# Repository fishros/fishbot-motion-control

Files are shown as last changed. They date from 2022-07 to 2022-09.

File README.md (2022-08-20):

# FishBot机器人运动控制板子-嵌入式驱动原理图PCB

## TODO&DONE
- [x] 电机驱动\编码器计算 
- [x] OLED驱动与显示
- [x] WIFI模块
- [x] 电机PID控制计算
- [x] Protocol数据接受及处理实现
- [x] Protocol数据发送处理及实现
- [x] MPU6050任务数据获取及姿态推算
- [x] UDP协议收发任务实现
- [ ] WIFI短线自动重连
- [ ] NVS掉电存储模块（WIFI配置、PID配置）
- [ ] 按键驱动实现（模式切换功能）
- [ ] 日志模块搭建（支持输出到UDPServer）
- [ ] 重新分配各个任务的优先级及空间大小
- [ ] 制定新版本协议（支持模式配置、WIFI配置，增加PID更多参数，冗余电机数量）
- [ ] 新版本协议WIFI模块实现
- [ ] 新版本协议PID模块实现
- [ ] 新版本协议电机模块实现

## 开发环境搭建

### 构建
```
docker run -it  --rm --privileged -v=/dev:/dev  -v `pwd`:`pwd` -w `pwd` espressif/idf:release-v4.4 idf.py build
```

### 查看

```
docker run -it  --rm --privileged -v=/dev:/dev  -v `pwd`:`pwd` -w `pwd` espressif/idf:release-v4.4 idf.py monitor
```

### 烧写
```
docker run -it  --rm --privileged -v=/dev:/dev  -v `pwd`:`pwd` -w `pwd` espressif/idf:release-v4.4 idf.py flash monitor
# Windows With Docker&WSL
esptool.py -p /dev/ttyS12 -b 921600  --before=default_reset --after=hard_reset write_flash --flash_mode dio --flash_freq 40m --flash_size 4MB 0x1000 bootloader/bootloader.bin 0x10000 main.bin 0x8000 partition_table/partition-table.bin
```

### Merge
```
docker run -it --rm --privileged -v=/dev:/dev  -v `pwd`:`pwd` -w `pwd` fishros2/fishbot-tool esptool.py --chip ESP8266 merge_bin -o fishbot_motion_control_v1.0.0.`date +%y%m%d`.bin --flash_mode dio --flash_size 4MB 0x1000 build/bootloader/bootloader.bin 0x8000 build/partition_table/partition-table.bin 0x10000 build/main.bin
```

## 工程介绍

```mermaid
graph TD;
protocol-->key
protocol-->motor
protocol-->oled
protocol-->imu
protocol-->wifi
key-->fishbot
motor-->fishbot
oled-->fishbot
imu-->fishbot
wifi-->fishbot
```

### 嵌入式驱动结构

目前组件目录

```
├── config
│   └── include
│       ├── config.h
│       └── task_config.h
├── drivers
│   ├── general
│   │   ├── key
│   │   ├── led
│   │   │   ├── include
│   │   │   │   └── led.h
│   │   │   └── led_esp32.c
│   │   ├── motors
│   │   │   └── motor
│   │   │       ├── include
│   │   │       │   └── motor.h
│   │   │       └── motor.c
│   │   └── wifi
│   │       ├── include
│   │       │   └── wifi.h
│   │       └── wifi.c
│   └── i2c_devices
│       ├── mpu6050
│       │   ├── include
│       │   │   ├── mpu6050.h
│       │   │   └── mpu6050_registers.h
│       │   └── mpu6050.c
│       └── oled
│           ├── include
│           │   └── oled.h
│           └── oled.c
├── fishbot
│   ├── fishbot.c
│   ├── fishbot_config.c
│   └── include
│       ├── fishbot_config.h
│       └── fishbot.h
├── libs
│   ├── esp32_i2c_rw
│   │   ├── esp32_i2c_rw.c
│   │   └── include
│   │       └── esp32_i2c_rw.h
│   ├── pid_controller
│   │   ├── include
│   │   │   └── pid_controller.h
│   │   └── pid_controller.c
│   └── rotary_encoder
│       ├── include
│       │   └── rotary_encoder.h
│       └── src
│           └── rotary_encoder_pcnt_ec11.c
└── protocol
    ├── proto
    │   ├── include
    │   │   └── protocol.h
    │   └── protocol.c
    ├── proto_utils
    │   ├── include
    │   │   ├── proto_utils.h
    │   │   └── proto_v1.0.0.20220621.h
    │   ├── proto_utils.c
    │   └── proto_v1.0.0.20220621.c
    ├── uart_protocol
    │   ├── include
    │   │   └── uart_protocol.h
    │   └── uart_protocol.c
    └── udp_client_protocol
        ├── include
        │   └── udp_client_protocol.h
        └── udp_client.c
```

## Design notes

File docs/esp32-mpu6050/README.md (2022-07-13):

# ESP32 MPU6050

Code provided in this repository is a MPU6050 library for ESP 32.

## Table of Contents

- [Components](#components)
  - [ESP 32](#esp-32)
  - [ESP-IDF](#esp-idf)
  - [MPU-6050](#mpu-6050)
- [Quick Start](#quick-start)
- [Acknowledgments](#acknowledgments)

## Components

To make this code work, you need the following components:

* This repository.
* [ESP 32](https://espressif.com/en/products/hardware/esp32/overview) module.
* [ESP-IDF](https://github.com/espressif/esp-idf).
* [MPU-6050](https://www.invensense.com/products/motion-tracking/6-axis/mpu-6050/) module.

### ESP 32

Any ESP 32 module should work.

### ESP-IDF

Configure your PC according to [ESP 32 Documentation](https://docs.espressif.com/projects/esp-idf/en/latest/?badge=latest?badge=latest). Windows, Linux and Mac OS are supported.

### MPU-6050

This example has been tested with a MPU-6050. 

The MPU-6000 should work aswell.

## Quick Start

This directory is an ESP-IDF component. Clone it (or add it as a submodule) into the component directory of the project.

To use this library you also need the [esp32-i2c_rw](https://github.com/gabrielbvicari/esp32-i2c_rw) library. Clone it in the same folder as you did with the MPU-6050.

To modify or understand the code please read the [MPU-6050 Datasheet](https://www.invensense.com/wp-content/uploads/2015/02/MPU-6000-Datasheet1.pdf) guide and the [ESP 32 Documentation](https://docs.espressif.com/projects/esp-idf/en/latest/?badge=latest?badge=latest).

## Acknowledgments

This application is using code based on:

* Implementation in C++ for ESP 32 by [Jeff Rowberg](https://www.i2cdevlib.com).

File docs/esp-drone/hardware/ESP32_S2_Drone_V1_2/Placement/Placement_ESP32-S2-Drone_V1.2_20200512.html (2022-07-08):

D:\WORK\#31436_ESP32-S2-ESPlane-KIT_M_V1.0_N_XX_20200325_V0.1\#31436_ESP32-S2-ESPlane-KIT_M_V1.2_N_XX_20200511_V0.3\02_PCB/PCB_ESP32-S2-Drone_V1.2_20200512.pcb Create in 2020/5/12 17:13:59 Total components = 203 component(s)

Component Report
NO. | RefDes | PartDecal | Pins | Layer | Orient | PositionX | PositionY | IsSMD
1 | C1 | C0603 | 2 | Top | 180 | 1571.554 | 2462.404 | Yes
2 | C2 | C0402 | 2 | Top | 90 | 1685.304 | 2562.104 | Yes
3 | C3 | C0603 | 2 | Top | 180 | 1555.454 | 2230.404 | Yes
4 | C4 | C0402 | 2 | Top | 270 | 1923.504 | 2559.904 | Yes
5 | C5 | C0402 | 2 | Top | 270 | 1771.004 | 2562.104 | Yes
6 | C6 | C0603 | 2 | Top | 0 | 2787.933 | 2016.722 | Yes
7 | C7 | C0402 | 2 | Top | 0 | 2808.406 | 1922.234 | Yes
8 | C8 | C0603 | 2 | Top | 180 | 2671.004 | 2016.722 | Yes
9 | C9 | C0402 | 2 | Top | 90 | 2750.925 | 1943.888 | Yes
10 | C10 | C0603 | 2 | Top | 180 | 1711.454 | 2230.404 | Yes
11 | C11 | C0603 | 2 | Top | 180 | 1706.504 | 2462.404 | Yes
12 | C12 | C0603 | 2 | Top | 180 | 1426.004 | 2117.254 | Yes
13 | C13 | C0402 | 2 | Top | 0 | 2231.004 | 2304.754 | Yes
14 | C14 | C0603 | 2 | Top | 90 | 2369.754 | 2361.004 | Yes
15 | C15 | C0603 | 2 | Top | 90 | 2169.754 | 2403.504 | Yes
16 | C16 | C0603 | 2 | Top | 180 | 2409.843 | 1237.402 | Yes
17 | C17 | C0402 | 2 | Top | 180 | 2398.031 | 1188.189 | Yes
18 | C18 | C0402 | 2 | Top | 270 | 1571.260 | 1214.173 | Yes
19 | C19 | C0402 | 2 | Top | 270 | 1852.254 | 2286.004 | Yes
20 | C20 | C0402 | 2 | Top | 0 | 2028.839 | 2377.254 | Yes
21 | C21 | C0402 | 2 | Top | 90 | 1959.604 | 2393.504 | Yes
22 | C22 | C0402 | 2 | Top | 180 | 1918.504 | 2141.004 | Yes
23 | C23 | C0402 | 2 | Top | 0 | 1139.370 | 1915.354 | Yes
24 | C24 | C0402 | 2 | Top | 0 | 1139.754 | 1604.754 | Yes
25 | D1 | SOD523 | 2 | Top | 315 | 1382.254 | 1399.754 | Yes
26 | D2 | SOD523 | 2 | Top | 45 | 1389.754 | 2547.254 | Yes
27 | D3 | SOD323 | 2 | Top | 90 | 2376.004 | 2237.254 | Yes
28 | D4 | SOD523 | 2 | Top | 135 | 2549.754 | 2552.254 | Yes
29 | D5 | SOD523 | 2 | Top | 0 | 2744.754 | 1419.754 | Yes
30 | D6 | LED3010-S | 3 | Top | 0 | 1476.378 | 2814.961 | Yes
31 | D7 | LED3010-S | 3 | Top | 180 | 1476.378 | 1122.047 | Yes
32 | D8 | LED3010-S | 3 | Top | 0 | 2460.630 | 2814.961 | Yes
33 | D9 | LED3010-S | 3 | Top | 180 | 2460.630 | 1122.047 | Yes
34 | FB1 | L0603 | 2 | Top | 90 | 2409.754 | 1328.504 | Yes
35 | H1 | P_2X1 | 1 | Bottom | 135 | 2814.964 | 2657.484 | Yes
36 | H58 | P_2X1 | 1 | Bottom | 45 | 708.661 | 3346.457 | Yes
37 | H59 | P_2X1 | 1 | Bottom | 45 | 1279.528 | 2814.961 | Yes
38 | H60 | P_2X1 | 1 | Bottom | 45 | 2657.480 | 1122.047 | Yes
39 | H61 | P_2X1 | 1 | Bottom | 45 | 3228.346 | 590.551 | Yes
40 | H62 | P_2X1 | 1 | Bottom | 135 | 1122.047 | 1279.528 | Yes
41 | H63 | P_2X1 | 1 | Bottom | 45 | 1122.047 | 2657.480 | Yes
42 | H65 | P_2X1 | 1 | Bottom | 45 | 3346.457 | 708.661 | Yes
43 | H66 | P_2X1 | 1 | Bottom | 135 | 2657.480 | 2814.961 | Yes
44 | H67 | P_2X1 | 1 | Bottom | 135 | 1279.528 | 1122.047 | Yes
45 | H68 | P_2X1 | 1 | Bottom | 135 | 590.551 | 708.661 | Yes
46 | H69 | P_2X1 | 1 | Bottom | 45 | 590.551 | 3228.346 | Yes
47 | H70 | P_2X1 | 1 | Bottom | 45 | 2814.961 | 1279.528 | Yes
48 | H71 | P_2X1 | 1 | Bottom | 135 | 3346.457 | 3228.346 | Yes
49 | H72 | P_2X1 | 1 | Bottom | 135 | 708.661 | 590.551 | Yes
50 | H73 | P_2X1 | 1 | Bottom | 135 | 3228.346 | 3346.457 | Yes
51 | J1 | USB_5P_MICRO_F | 11 | Top | 180 | 2638.504 | 2303.504 | No
52 | J2 | FFC24-0P5 | 26 | Top | 180 | 1968.504 | 2736.220 | Yes
53 | J3 | A2005HWV-S-XP-A | 16 | Top | 270 | 2460.630 | 1751.969 | No
54 | J4 | A2005HWV-S-XP-A | 16 | Top | 270 | 1476.378 | 1751.969 | No
55 | J5 | CON2X1_1P5_SMT_ZH-2A_DIP | 4 | Top | 45 | 2678.504 | 2678.504 | No
56 | J6 | CON2X1_1P5_SMT_ZH-2A_DIP | 4 | Top | 315 | 2678.504 | 1258.504 | No
57 | J7 | CON2X1_2P0_SMT_PH2A-S-A | 4 | Top | 270 | 1478.346 | 2288.504 | Yes
58 | J8 | CON2X1_1P5_SMT_ZH-2A_DIP | 4 | Top | 225 | 1258.504 | 1258.504 | No
59 | J9 | CON2X1_1P5_SMT_ZH-2A_DIP | 4 | Top | 135 | 1258.504 | 2678.504 | No
60 | J10 | A2005HWV-S-XP-A | 16 | Top | 270 | 1476.378 | 463.219 | No
61 | J11 | A2005HWV-S-XP-A | 16 | Top | 270 | 2460.630 | 463.219 | No
62 | Q3 | SOT-23-3 | 3 | Top | 180 | 1291.334 | 2033.504 | Yes
63 | Q4 | SOT-23-3 | 3 | Top | 0 | 1218.504 | 1512.004 | Yes
64 | Q5 | SOT-23-3 | 3 | Top | 270 | 1518.504 | 2667.254 | Yes
65 | Q6 | SOT-23-3 | 3 | Top | 90 | 2418.504 | 2667.504 | Yes
66 | Q7 | SOT-23-3 | 3 | Top | 0 | 2718.504 | 1512.004 | Yes
67 | R1 | R0402 | 2 | Top | 180 | 2533.504 | 2143.504 | Yes
68 | R3 | R0402 | 2 | Top | 0 | 2454.754 | 2143.504 | Yes
69 | R5 | R0402 | 2 | Top | 90 | 1868.404 | 2559.904 | Yes
70 | R6 | R0402 | 2 | Top | 270 | 1736.904 | 2562.104 | Yes
71 | R7 | R0402 | 2 | Top | 90 | 2709.193 | 1943.888 | Yes
72 | R8 | R0402 | 2 | Top | 0 | 2808.012 | 1963.967 | Yes
73 | R9 | R0402 | 2 | Top | 0 | 2646.201 | 1929.321 | Yes
74 | R10 | R0402 | 2 | Top | 0 | 2646.201 | 1964.754 | Yes
75 | R11 | R0402 | 2 | Top | 90 | 1321.260 | 1581.890 | Yes
76 | R12 | R0402 | 2 | Top | 90 | 1356.693 | 1581.890 | Yes
77 | R13 | R0402 | 2 | Top | 180 | 1232.254 | 1604.754 | Yes
78 | R14 | R0402 | 2 | Top | 180 | 1675.504 | 2619.904 | Yes
79 | R15 | R0402 | 2 | Top | 90 | 2583.996 | 1996.348 | Yes
80 | R16 | R0402 | 2 | Top | 270 | 2583.996 | 1916.148 | Yes
81 | R17 | R0402 | 2 | Top | 0 | 1253.504 | 2123.504 | Yes
82 | R18 | R0402 | 2 | Top | 180 | 2231.004 | 2267.854 | Yes
83 | R19 | R0402 | 2 | Top | 0 | 1139.754 | 1871.004 | Yes
84 | R20 | R0402 | 2 | Top | 90 | 2287.254 | 2288.504 | Yes
85 | R21 | R0402 | 2 | Top | 180 | 1538.976 | 1357.480 | Yes
86 | R22 | R0402 | 2 | Top | 90 | 1536.614 | 1214.173 | Yes
87 | R23 | R0402 | 2 | Top | 180 | 2381.004 | 2563.504 | Yes
88 | R24 | R0402 | 2 | Top | 90 | 2622.254 | 1529.754 | Yes
89 | R25 | R0402 | 2 | Top | 180 | 1538.976 | 1397.638 | Yes
90 | R26 | R0402 | 2 | Top | 180 | 1516.004 | 2763.504 | Yes
91 | R27 | R0402 | 2 | Top | 0 | 2018.604 | 2121.004 | Yes
92 | R28 | R0402 | 2 | Top | 0 | 1887.254 | 2377.254 | Yes
93 | R29 | R0402 | 2 | Top | 90 | 1448.504 | 1214.754 | Yes
94 | R30 | R0402 | 2 | Top | 180 | 2499.754 | 2763.504 | Yes
95 | R31 | R0402 | 2 | Top | 0 | 2476.772 | 1188.189 | Yes
96 | R32 | R0402 | 2 | Top | 270 | 2086.004 | 2360.504 | Yes
97 | R33 | R0402 | 2 | Top | 90 | 2086.004 | 2280.504 | Yes
98 | R34 | R0402 | 2 | Top | 0 | 1282.254 | 1759.754 | Yes
99 | R35 | R0402 | 2 | Top | 90 | 1344.754 | 1702.254 | Yes
100 | SW1 | SW4_3X3P5X1P1_SMT | 6 | Top | 270 | 1141.704 | 2047.244 | No
101 | SW2 | SW4_3X3P5X1P1_SMT | 6 | Top | 270 | 1141.732 | 1740.157 | No
102 | T1 | K_3X2 | 1 | Top | 0 | 68.504 | 2242.504 | No
103 | T2 | K_3X2 | 1 | Top | 0 | 68.504 | 2095.504 | No
104 | T3 | K_3X2 | 1 | Top | 0 | 720.472 | 2242.504 | No
105 | T4 | K_3X2 | 1 | Top | 0 | 720.472 | 2095.504 | No
106 | T5 | K_3X2 | 1 | Top | 0 | 68.504 | 1841.504 | No
107 | T6 | K_3X2 | 1 | Top | 0 | 68.504 | 1694.504 | No
108 | T7 | K_3X2 | 1 | Top | 0 | 720.474 | 1841.504 | No
109 | T8 | K_3X2 | 1 | Top | 0 | 720.472 | 1694.504 | No
110 | T9 | K_3X2 | 1 | Top | 180 | 1648.504 | 3512.254 | No
111 | T10 | K_3X2 | 1 | Top | 180 | 1648.504 | 3366.004 | No
112 | T11 | K_3X2 | 1 | Top | 180 | 3868.504 | 2242.504 | No
113 | T12 | K_3X2 | 1 | Top | 180 | 3868.504 | 2094.754 | No
114 | T13 | K_3X2 | 1 | Top | 180 | 2276.504 | 3512.254 | No
115 | T14 | K_3X2 | 1 | Top | 180 | 2276.504 | 3366.004 | No
116 | T15 | K_3X2 | 1 | Top | 180 | 3868.504 | 1841.504 | No
117 | T16 | K_3X2 | 1 | Top | 180 | 3868.504 | 1694.754 | No
118 | T17 | K_3X2 | 1 | Top | 0 | 3216.504 | 2242.504 | No
119 | T18 | K_3X2 | 1 | Top | 0 | 3216.504 | 2095.504 | No
120 | T19 | K_3X2 | 1 | Top | 0 | 3216.504 | 1841.504 | No
121 | T20 | K_3X2 | 1 | Top | 0 | 3216.504 | 1694.504 | No
122 | T21 | SMD_3X6 | 1 | Top | 225 | 3359.055 | 495.669 | No
123 | T22 | HOLE_0P6 | 1 | Top | 0 | 717.649 | 2527.559 | No
124 | T23 | SMD_3X6 | 1 | Top | 45 | 3881.102 | 136.220 | No
125 | T24 | SMD_3X6 | 1 | Top | 135 | 3813.386 | 3888.583 | No
126 | T25 | SMD_3X6 | 1 | Top | 315 | 3446.063 | 3375.591 | No
127 | T26 | SMD_3X6 | 1 | Top | 225 | 47.638 | 3812.205 | No
128 | T27 | SMD_3X6 | 1 | Top | 45 | 585.039 | 3433.071 | No
129 | T28 | SMD_3X6 | 1 | Top | 135 | 497.638 | 582.677 | No
130 | T29 | SMD_3X6 | 1 | Top | 315 | 124.409 | 45.669 | No
131 | T30 | HOLE_0P6 | 1 | Top | 0 | 717.649 | 2500.000 | No
132 | T31 | HOLE_0P6 | 1 | Top | 0 | 717.649 | 2472.441 | No
133 | T32 | HOLE_0P6 | 1 | Top | 0 | 717.649 | 2417.323 | No
134 | T33 | HOLE_0P6 | 1 | Top | 0 | 717.649 | 1519.685 | No
135 | T34 | HOLE_0P6 | 1 | Top | 0 | 717.649 | 1492.126 | No
136 | T35 | HOLE_0P6 | 1 | Top | 0 | 717.649 | 1464.567 | No
137 | T36 | HOLE_0P6 | 1 | Top | 0 | 717.649 | 1409.449 | No
138 | T37 | HOLE_0P6 | 1 | Top | 0 | 717.649 | 1437.008 | No
139 | T38 | HOLE_0P6 | 1 | Top | 0 | 1076.772 | 1519.685 | No
140 | T39 | HOLE_0P6 | 1 | Top | 0 | 1076.772 | 1492.126 | No
141 | T40 | HOLE_0P6 | 1 | Top | 0 | 1076.772 | 1464.567 | No
142 | T41 | HOLE_0P6 | 1 | Top | 0 | 1076.772 | 1409.449 | No
143 | T42 | HOLE_0P6 | 1 | Top | 0 | 1076.772 | 1437.008 | No
144 | T43 | HOLE_0P6 | 1 | Top | 0 | 1076.772 | 2531.496 | No
145 | T44 | HOLE_0P6 | 1 | Top | 0 | 1076.772 | 2503.937 | No
146 | T45 | HOLE_0P6 | 1 | Top | 0 | 1076.772 | 2476.378 | No
147 | T46 | HOLE_0P6 | 1 | Top | 0 | 1076.772 | 2448.819 | No
148 | T47 | HOLE_0P6 | 1 | Top | 0 | 1076.772 | 2421.260 | No
149 | T48 | HOLE_0P6 | 1 | Top | 0 | 3219.359 | 2531.496 | No
150 | T49 | HOLE_0P6 | 1 | Top | 0 | 3219.359 | 2503.937 | No
151 | T50 | HOLE_0P6 | 1 | Top | 0 | 3219.359 | 2476.378 | No
152 | T51 | HOLE_0P6 | 1 | Top | 0 | 3219.359 | 2448.819 | No
153 | T52 | HOLE_0P6 | 1 | Top | 0 | 3219.359 | 2421.260 | No
154 | T53 | HOLE_0P6 | 1 | Top | 0 | 3219.359 | 1515.748 | No
155 | T54 | HOLE_0P6 | 1 | Top | 0 | 3219.359 | 1488.189 | No
156 | T55 | HOLE_0P6 | 1 | Top | 0 | 3219.359 | 1460.630 | No
157 | T56 | HOLE_0P6 | 1 | Top | 0 | 3219.359 | 1433.071 | No
158 | T57 | HOLE_0P6 | 1 | Top | 0 | 3219.359 | 1405.512 | No
159 | T58 | HOLE_0P6 | 1 | Top | 0 | 717.649 | 2444.882 | No
160 | T59 | HOLE_0P6 | 1 | Top | 0 | 2860.236 | 1519.685 | No
161 | T60 | HOLE_0P6 | 1 | Top | 0 | 2860.236 | 1492.126 | No
162 | T61 | HOLE_0P6 | 1 | Top | 0 | 2860.236 | 1464.567 | No
163 | T62 | HOLE_0P6 | 1 | Top | 0 | 2860.236 | 1437.008 | No
164 | T63 | HOLE_0P6 | 1 | Top | 0 | 2860.236 | 1409.449 | No
165 | T64 | HOLE_0P6 | 1 | Top | 0 | 2860.236 | 2531.496 | No
166 | T65 | HOLE_0P6 | 1 | Top | 0 | 2860.236 | 2503.937 | No
167 | T66 | HOLE_0P6 | 1 | Top | 0 | 2860.236 | 2476.378 | No
168 | T67 | HOLE_0P6 | 1 | Top | 0 | 2860.236 | 2448.819 | No
169 | T68 | HOLE_0P6 | 1 | Top | 0 | 2860.236 | 2421.260 | No
170 | T69 | HOLE_0P6 | 1 | Top | 0 | 1549.291 | 1074.803 | No
171 | T70 | HOLE_0P6 | 1 | Top | 0 | 1576.850 | 1074.803 | No
172 | T71 | HOLE_0P6 | 1 | Top | 0 | 1604.409 | 1074.803 | No
173 | T72 | HOLE_0P6 | 1 | Top | 0 | 1631.969 | 1074.803 | No
174 | T73 | HOLE_0P6 | 1 | Top | 0 | 1549.291 | 925.197 | No
175 | T74 | HOLE_0P6 | 1 | Top | 0 | 1576.850 | 925.197 | No
176 | T75 | HOLE_0P6 | 1 | Top | 0 | 1604.409 | 925.197 | No
177 | T76 | HOLE_0P6 | 1 | Top | 0 | 1631.969 | 925.197 | No
178 | T77 | HOLE_0P6 | 1 | Top | 0 | 2305.315 | 925.197 | No
179 | T78 | HOLE_0P6 | 1 | Top | 0 | 2332.874 | 925.197 | No
180 | T79 | HOLE_0P6 | 1 | Top | 0 | 2360.433 | 925.197 | No
181 | T80 | HOLE_0P6 | 1 | Top | 0 | 2387.992 | 925.197 | No
182 | T81 | HOLE_0P6 | 1 | Top | 0 | 2305.315 | 1074.803 | No
183 | T82 | HOLE_0P6 | 1 | Top | 0 | 2332.874 | 1074.803 | No
184 | T83 | HOLE_0P6 | 1 | Top | 0 | 2360.433 | 1074.803 | No
185 | T84 | HOLE_0P6 | 1 | Top | 0 | 2387.992 | 1074.803 | No
186 | T85 | HOLE_0P6 | 1 | Top | 0 | 1913.386 | 3464.567 | No
187 | T86 | HOLE_0P6 | 1 | Top | 0 | 1940.945 | 3464.567 | No
188 | T87 | HOLE_0P6 | 1 | Top | 0 | 1968.504 | 3464.567 | No
189 | T88 | HOLE_0P6 | 1 | Top | 0 | 1996.063 | 3464.567 | No
190 | T89 | HOLE_0P6 | 1 | Top | 0 | 2023.622 | 3464.567 | No
191 | T91 | HOLE_0P6 | 1 | Top | 0 | 1913.386 | 2862.205 | No
192 | T92 | HOLE_0P6 | 1 | Top | 0 | 1940.945 | 2862.205 | No
193 | T93 | HOLE_0P6 | 1 | Top | 0 | 1968.504 | 2862.205 | No
194 | T94 | HOLE_0P6 | 1 | Top | 0 | 1996.063 | 2862.205 | No
195 | T95 | HOLE_0P6 | 1 | Top | 0 | 2023.622 | 2862.205 | No
196 | U1 | SOT23-6 | 6 | Top | 270 | 2493.504 | 2253.504 | Yes
197 | U2 | SOT-23-5 | 5 | Top | 90 | 1500.354 | 2313.104 | Yes
198 | U3 | QFN28_0P5_5 | 29 | Top | 180 | 2688.720 | 1776.959 | Yes
199 | U4 | SOT-23-5 | 5 | Top | 90 | 1656.354 | 2313.104 | Yes
200 | U5 | DFN3030-8 | 9 | Top | 270 | 2264.754 | 2392.254 | Yes
201 | U6 | ESP32-S2-WROVER | 43 | Top | 180 | 2322.835 | 834.646 | Yes
202 | U7 | QFN24_0P5_4_A | 24 | Top | 180 | 1968.504 | 2256.204 | Yes
203 | U8 | SOT363 | 6 | Top | 90 | 1284.754 | 1689.754 | Yes

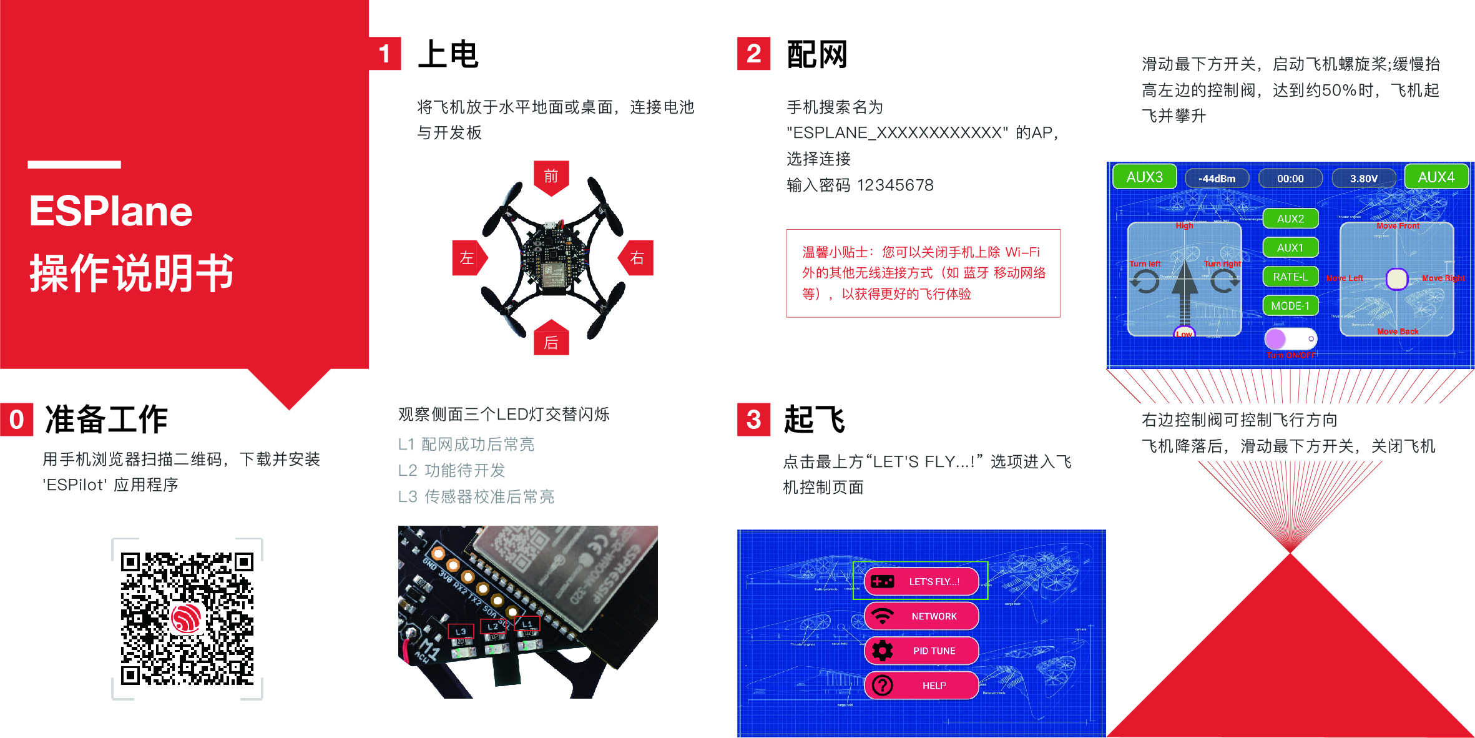
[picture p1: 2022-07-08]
docs/esp-drone/docs/_static/esplane_v1_specification.jpg

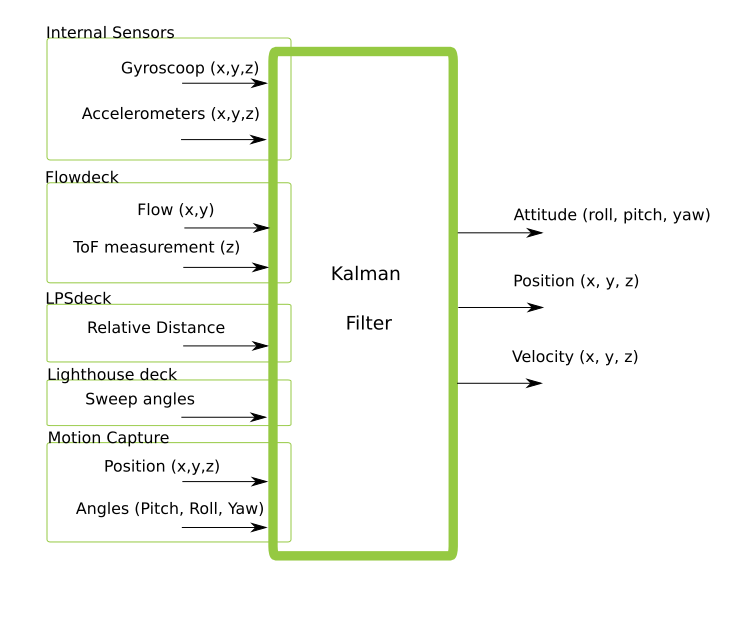
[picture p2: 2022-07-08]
docs/esp-drone/docs/_static/Schematic-overview-of-inputs-and-outputs-of-the-Extended-Kalman-Filter.png

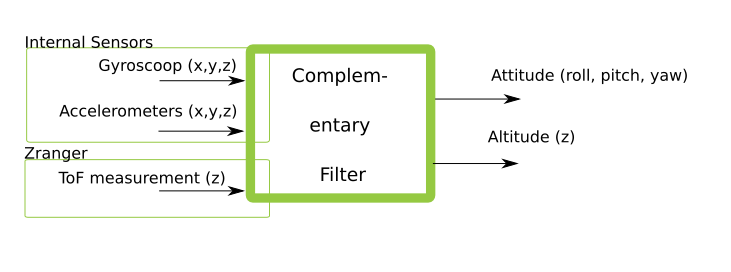
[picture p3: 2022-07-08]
docs/esp-drone/docs/_static/Schematic-overview-of-inputs-and-outputs-of-the-Complementary-filter.png

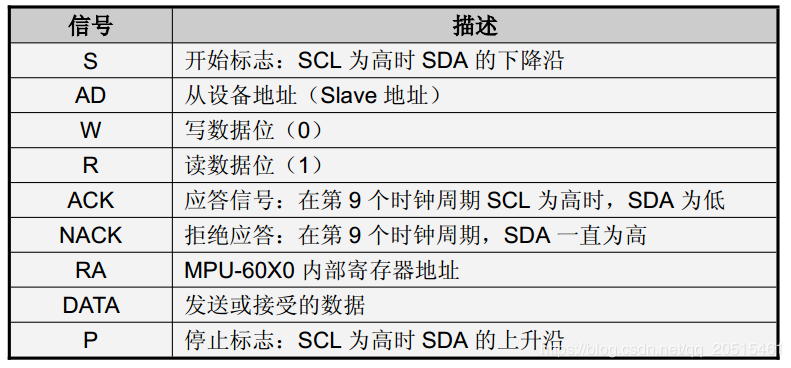
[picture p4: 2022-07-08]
docs/esp-drone/docs/_static/i2c_signal.png

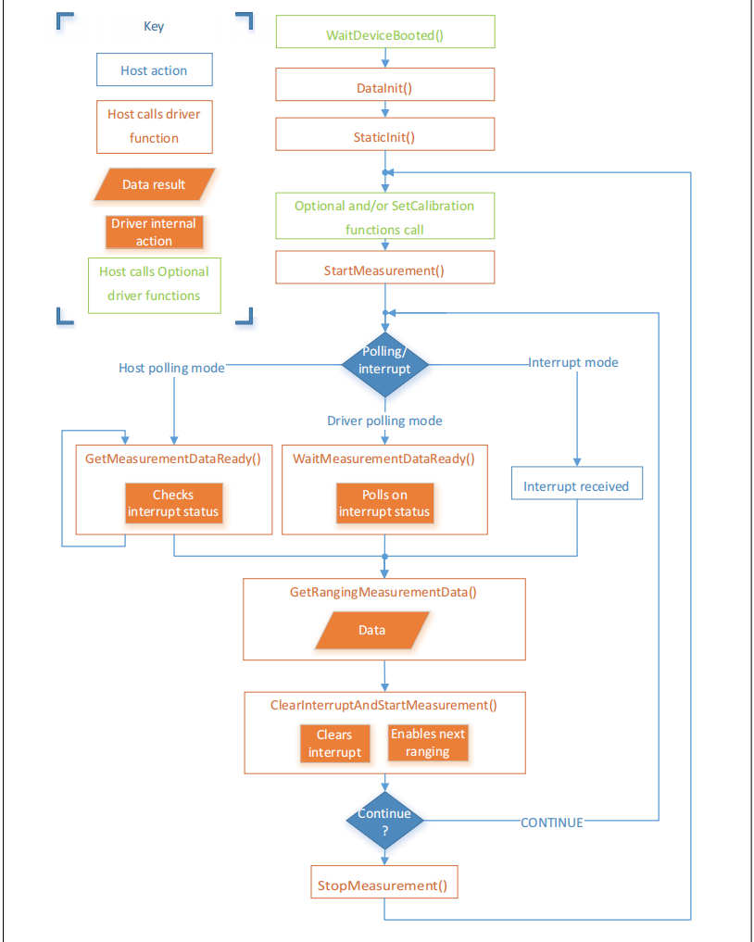
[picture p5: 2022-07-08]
docs/esp-drone/docs/_static/vl53lxx_meaturement_sequence.png

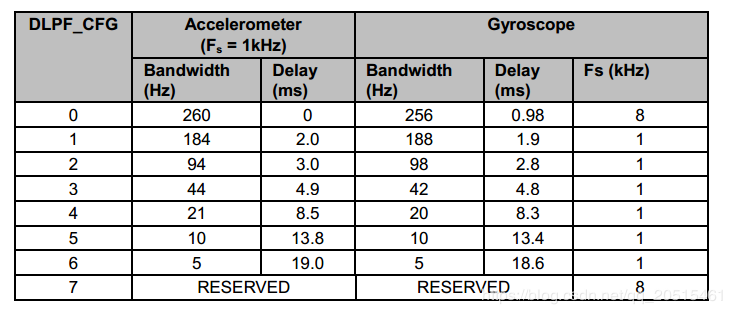
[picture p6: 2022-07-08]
docs/esp-drone/docs/_static/DLPF_CFG.png

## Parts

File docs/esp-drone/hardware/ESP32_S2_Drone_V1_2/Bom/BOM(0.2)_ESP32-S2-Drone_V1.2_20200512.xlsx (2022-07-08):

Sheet: ESP32-S2-Drone
BOM(V0.2)_ESP32-S2-Drone_V1.2
ID | Qty | Ref Des | Value | Package | Description | Manufacturer | Manufacturer Part # | Notes
1 | 8 | C1,C3,C10,C11,C12,C14,C15,C16 | 10uF/10V | C0603 | 陶瓷电容
2 | 9 | C2,C4,C5,C7,C9,C17,C18,C19,C21 | 0.1uF/10V | C0402 | 陶瓷电容
3 | 2 | C6,C8 | 4.7uF/10V | C0603 | 陶瓷电容
4 | 1 | C13 | 470pF/25V | C0402 | 陶瓷电容
5 | 1 | C20 | 10nF/25V | C0402 | 陶瓷电容
6 | 1 | C22 | 2.2nF/25V | C0402 | 陶瓷电容
7 | 0 | C23,C24 | 0.1uF/10V(NC) | C0402 | 陶瓷电容 |  |  | 不贴件
8 | 4 | D1,D2,D4,D5 | 1N4148WT | SOD523 | 开关二极管 | 长电科技 | 1N4148WT
9 | 1 | D3 | BAT60B | SOD323 | 肖特基二极管 | Infineon | BAT60B
10 | 1 | D6 | LED-WHT | LED3010-S | LED,白色 | Everlight | 12-21/T3D-APQHY/2C
11 | 1 | D7 | LED-BLE | LED3010-S | LED,蓝色 | Everlight | 12-21/BHC-ZL2N1TY/2C
12 | 1 | D8 | LED-RED | LED3010-S | LED,红色 | Everlight | 12-21/R8C-AN1P2B/2D
13 | 1 | D9 | LED-GRN | LED3010-S | LED,绿色 | Everlight | 12-21/GHC-YQ1R1B18Y/2C
14 | 1 | FB1 | BLM18SG331TN1D | L0603 | 磁珠,330R at 100MHz,1A | Murata | BLM18SG331TN1D
15 | 1 | J1 | USB-MICRO-B | USB_5P_MICRO_F | USB MicroB 连接器,四脚插板,无柱,卷边
16 | 1 | J2 | FFC-24P | FFC24-0P5 | FPC连接器,24P,间距0.5MM,翻盖式,下接
17 | 4 | J3,J4,J10,J11 | CON8-S-2P54 | A2005HWV-S-XP-A | 单排排母,8P,间距2.0mm,错位贴片,A型 | 长江连接器 | A2005HWV-S-8P-A
18 | 0 | J5,J6,J8,J9 | CON2-SB-ZH(NC) | CON2X1_1P5_SMT_ZH-2A_DIP | 针座,2P,ZH,侧入贴片 |  |  | 不贴件
19 | 1 | J7 | CON2-SB-PH | CON2X1_2P0_SMT_PH2A-S-A | 针座,2P,PH,侧入贴片
20 | 1 | Q3 | AO3401A | SOT-23-3 | PMOS | AOS | AO3401A
21 | 4 | Q4,Q5,Q6,Q7 | IRLML6344TRPbF | SOT-23-3 | Power NMOS | Infineon | IRLML6344TRPbF
22 | 3 | R1,R3,R6 | 0R/1% | R0402 | 贴片电阻
23 | 19 | R5,R8,R11,R12,R13,R14,R15,R16,R21,R22,R23,R24,R25,R27,R28,R32,R33,R34,R35 | 10K/1% | R0402 | 贴片电阻
24 | 1 | R7 | 22.1K/1% | R0402 | 贴片电阻
25 | 1 | R9 | 47.5K/1% | R0402 | 贴片电阻
26 | 3 | R10,R17,R19 | 82K/1% | R0402 | 贴片电阻
27 | 1 | R18 | 52.3K/1% | R0402 | 贴片电阻
28 | 1 | R20 | 29.4K/1% | R0402 | 贴片电阻
29 | 4 | R26,R29,R30,R31 | 1.5K/1% | R0402 | 贴片电阻
30 | 2 | SW1,SW2 | Button-3X3.5 | SW4_3X3P5X1P1_SMT | 轻触开关,侧按贴片,3mmX3.5mm | ALPS | SKSCLBE010
31 | 1 | U1 | USBLC6-2SC6 | SOT23-6 | ESD二极管 | ST | USBLC6-2SC6
32 | 1 | U2 | ME6211C28M5G-N | SOT-23-5 | LDO,2.8V | 微盟 | ME6211C28M5G-N
33 | 1 | U3 | CP2102N-A02 | QFN28_0P5_5 | USB to UART IC | Silicon Labs | CP2102N-A02
34 | 1 | U4 | ME6211C15M5G-N | SOT-23-5 | LDO,1.5V | 微盟 | ME6211C15M5G-N
35 | 1 | U5 | SGM2205-ADJ | DFN3030-8 | LDO,可调 | 圣邦微 | SGM2205-ADJ
36 | 1 | U6 | ESP32-S2-WROVER | ESP32-S2-WROVER | WiFi Module | Espressif | ESP32-S2-WROVER
37 | 1 | U7 | MPU-6050 | QFN24_0p5_4_A | 6轴运动传感器IC | InvenSense | MPU-6050
38 | 1 | U8 | BC847BDW1T1G | SOT363 | NPN Transistor,双路 | ON Semi | BC847BDW1T1G
39 | 1 | 非贴片物料 | 无人机锂电池 | NA | 动力型,300mAh,PH2.0,正向 |  |  | 参考链接 https://m.tb.cn/h.V8gEksR?sm=858897
40 | 4 | 非贴片物料 | 空心杯电机 | NA | 尺寸716,电压3.7v,50000转 |  |  | 参考链接 https://m.tb.cn/h.VR4sgSA?sm=2d0222
41 | 2 | 非贴片物料 | 螺旋桨A | NA | 尺寸46mm,0.75mm孔径,A螺旋桨 |  |  | 参考链接 https://m.tb.cn/h.VinQLQu?sm=185f2b
42 | 2 | 非贴片物料 | 螺旋桨B | NA | 尺寸46mm,0.75mm孔径,B螺旋桨 |  |  | 参考链接 https://m.tb.cn/h.VinQLQu?sm=185f2b
43 | 4 | 非贴片物料 | 电机密封圈 | NA | 孔径7mm,黑色 |  |  | 参考链接 https://m.tb.cn/h.VRfYUIN?sm=1dbc9d

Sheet: Sheet2
39 | 1 | NA | 无人机锂电池 | NA | 动力型300mah PH2.0 正向 | 参考链接 https://m.tb.cn/h.V8gEksR?sm=858897
40 | 4 | NA | 空心杯电机 | NA | 尺寸716 电压3.7v 50000 | 参考链接 https://m.tb.cn/h.VR4sgSA?sm=2d0222
41 | 2 | NA | 螺旋桨A | NA | 尺寸46mm 0.75mm孔径 A螺旋桨 | 参考链接 https://m.tb.cn/h.VinQLQu?sm=185f2b
42 | 2 | NA | 螺旋桨B | NA | 尺寸46mm 0.75mm孔径 B螺旋桨 | 参考链接 https://m.tb.cn/h.VinQLQu?sm=185f2b
43 | 4 | NA | 电机密封圈 | NA | 7mm孔径黑色 | 参考链接 https://m.tb.cn/h.VRfYUIN?sm=1dbc9d

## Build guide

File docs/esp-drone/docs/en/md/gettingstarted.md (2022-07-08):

# 快速入门

## 项目简介

ESP-Drone 是基于乐鑫 ESP32/ESP32-S2 开发的小型无人机解决方案，可使用手机 APP 或游戏手柄通过 Wi-Fi 网络进行连接和控制，目前已支持自稳定飞行、定高飞行、定点飞行等多种模式。该方案硬件结构简单，代码架构清晰，支持功能扩展，可用于 STEAM 教育等领域。项目部分代码来自 Crazyflie 开源工程，继承 GPL3.0 开源协议。

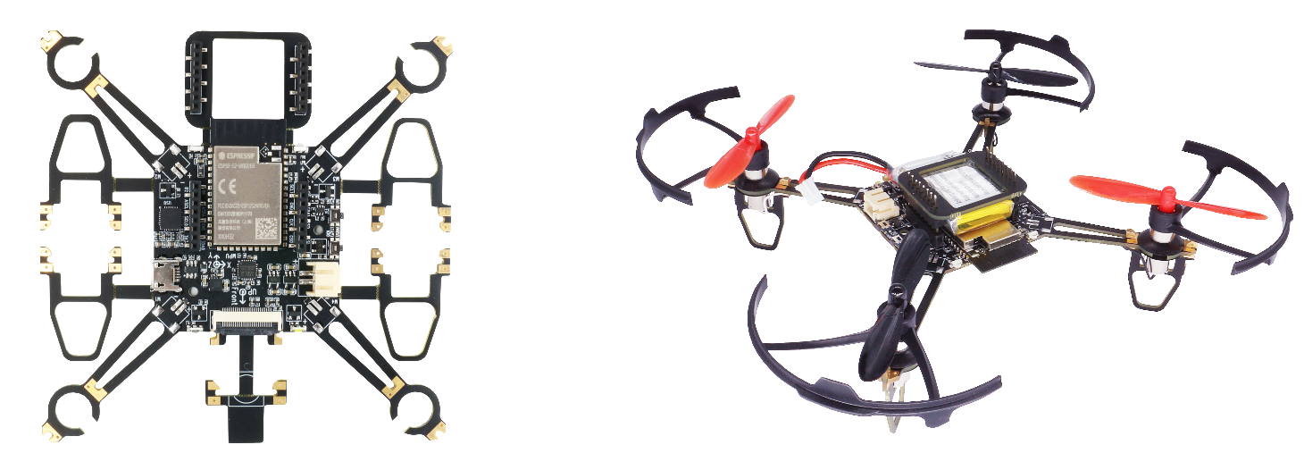
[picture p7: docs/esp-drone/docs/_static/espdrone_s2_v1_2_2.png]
ESP-Drone


* 支持自稳定模式-stabilize：自动控制机身水平，保持平稳飞行
* 支持定高模式-heighthold：自动控制油门输出，保持固定高度
* 支持定点模式-positionhold：自动控制机身角度，保持固定空间位置
* 支持 PC 上位机调试：使用 cfclient 上位机进行静态/动态调试
* 支持 APP 控制：使用手机 APP 通过 Wi-Fi 轻松控制
* 支持游戏手柄控制-gamepad：通过 cfclient 使用游戏手柄轻松控制

**ESP-Drone 2.0 使用模块化的设计思路，由主控板和扩展板组成：**

* **主控制板**：搭载 ESP32-S2 模组和支持基础飞行的必要传感器，并提供硬件扩展接口
* **扩展板**：搭载扩展传感器，可对接主控制板硬件扩展接口，支持高级飞行功能

|序号| 模块名 | 主要元器件 | 功能 | 接口 |安装位置 |
|--|--|--|--|--|--|
|1| **主控制板-ESP32-S2** |  ESP32-S2-WROVER + MPU6050| 基础飞行 |提供 I2C SPI GPIO 扩展接口  ||
|2|扩展板- **定点模块** |  PMW3901 + VL53L1X | 室内定点飞行 | SPI + I2C | 底部，面向地面 |
|3| 扩展板-**气压定高模块** |  MS5611 气压 | 气压定高 | I2C 或 MPU6050从机|顶部或底部 |
|4| 扩展板-指南针模块 |  HMC5883 罗盘 | 无头模式等高级模式 | I2C 或 MPU6050从机|顶部或底部 |

详情可查阅：[hardware](./hardware.md)

## ESP-IDF 简介

ESP-IDF 是乐鑫为 ESP32/ESP32-S2 提供的物联网开发框架。

* ESP-IDF 包含一系列库及头文件，提供了基于 ESP32/ESP32-S2 构建软件项目所需的核心组件。
* ESP-IDF 还提供了开发和量产过程中最常用的工具及功能，例如：构建、烧录、调试和测量等。

详情可查阅：[ESP-IDF Get Started](https://docs.espressif.com/projects/esp-idf/en/latest/esp32s2/get-started/index.html)

## Crazyflie 简介

Crazyflie 是来自 bitcraze 开源工程的四旋翼飞行器。

* Crazyflie 支持多种传感器组合，可以轻松实现定高模式、定点模式等高级飞行模式。
* Crazyflie 基于 FreeRTOS 编写，将复杂的无人机系统，分解成多个具有不同优先级的软件任务。
* Crazyflie 设计了功能完备的 cfclient 上位机和 CRTP 通信协议，便于实现调试、测量和控制。

A swarm of drones exploring the environment, avoiding obstacles and each other. \(Guus Schoonewille, TU Delft\)

>图片来源：A swarm of drones exploring the environment, avoiding obstacles and each other. \(Guus Schoonewille, TU Delft\)

详情可查阅 crazyflie 官网：[https://www.bitcraze.io/](https://www.bitcraze.io/)

## 准备工作

### 硬件组装

ESP-Drone_S2_V1.2：

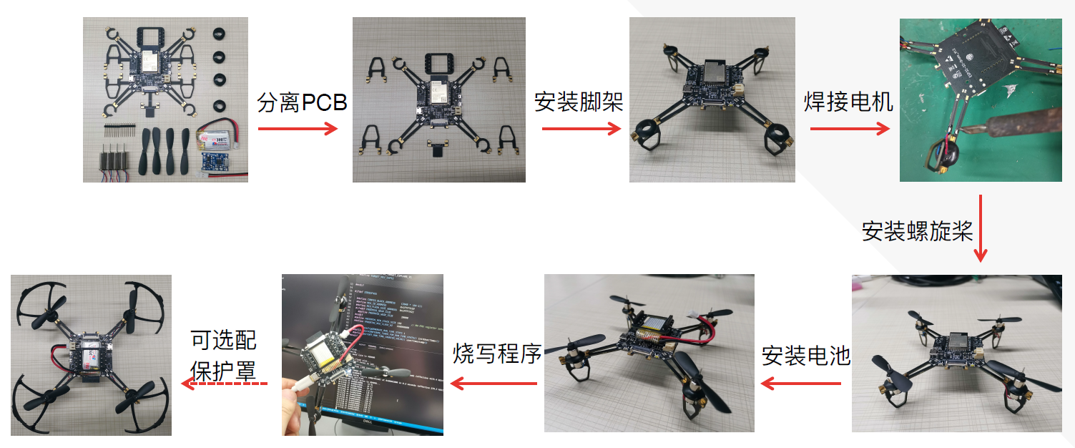
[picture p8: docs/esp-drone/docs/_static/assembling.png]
assembling


详细的硬件介绍和引脚资源分配可查阅：[hardware](./hardware.md)

### 安装 ESPDroe APP

**Android APP 下载：**

[https://github.com/qljz1993/DailyMD_public/raw/master/esplanes2_test/ESP-Drone-android-debug.apk](https://github.com/qljz1993/DailyMD_public/raw/master/esplanes2_test/ESP-Drone-android-debug.apk)

**IOS APP 扫码下载：**

<div align="center">
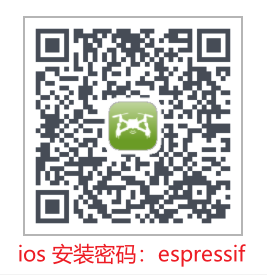
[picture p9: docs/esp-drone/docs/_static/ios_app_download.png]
ios_app_download
   
</div>

### 安装 CFClient

> 安装 CFClient 为可选步骤，用于实现高级调试，非必须使用

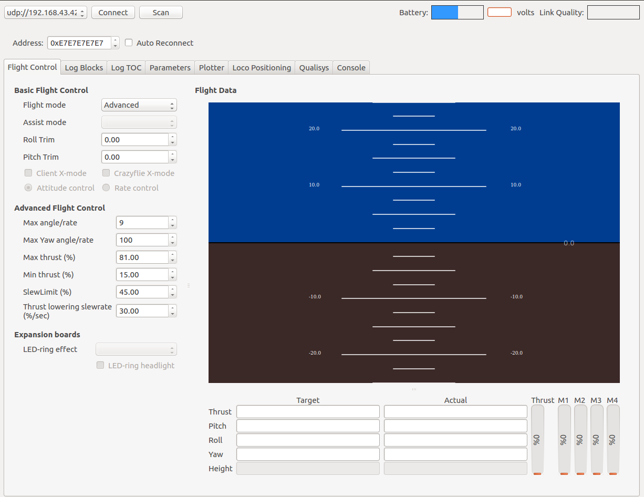
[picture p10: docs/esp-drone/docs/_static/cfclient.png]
cfclient


**1.安装crtp协议支持包**

1.1 下载源代码 

```text
git clone -b esp-drone  https://github.com/qljz1993/crazyflie-lib-python.git
```

1.2 进入源码目录，安装依赖 

```text
pip3 install -r requirements.txt
```

1.3 安装crtp包 

```text
pip3 install -e .
```

**2.安装cfclient**

2.1 下载源代码

```text
git clone -b esp-drone https://github.com/qljz1993/crazyflie-clients-python.git
```

2.2  进入源码目录，安装依赖 

```text
sudo apt-get install python3 python3-pip python3-pyqt5 python3-pyqt5.qtsvg
```

2.3  安装cfclient客户端

```text
pip3 install -e .
```

2.4 启动客户端

```text
python3 ./bin/cfclient
```

**3.配置遥控器**

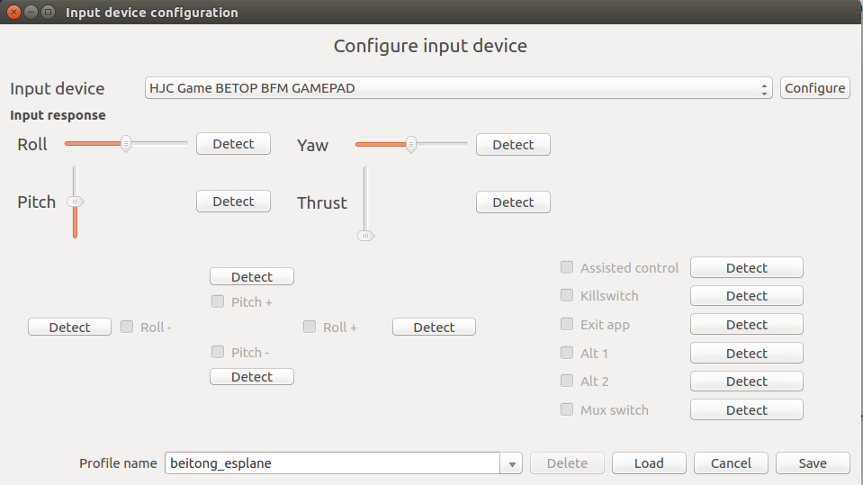
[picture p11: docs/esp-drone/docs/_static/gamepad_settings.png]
gamepad_settings


3.1 配置4个控制轴 `Roll 、Pitch、Yaw、Thrust`

3.2 配置一个按键为`Assisted control` ，用于飞行模式切换

## 手机 APP 使用指引

１. WiFi 连接

    SSID：ESPDRONE_XXXX (XXXX根据 MAC 设置） PASSWORD：12345678

２. 个性化设置

	```
	默认配置：

	Flight control settings 
		1. Mode: Mode2
		2. Deadzone: 0.2
		3. Roll trim: 0.0
		4. Pitch trim: 0.0
		5. Advanced flight control : true
		6. Advanced flight control preferences 
			1. max roll/pitch angle: 15
			2. max yaw angle: 90
			3. max thrust: 90
			4. min thrust: 25
			5. X-Mode: true
	Controller settings 
		1. use full travel for thrust: false
		2. virtual joystick size: 100
	App settings
		1. Screen rotation lock: true
		2. full screen mode:true
		3. show console: true   
	```

３. 控制飞行

  1. 打开通信连接，小飞机绿灯将闪烁
  2. 轻推油门，起飞

<div align="center">
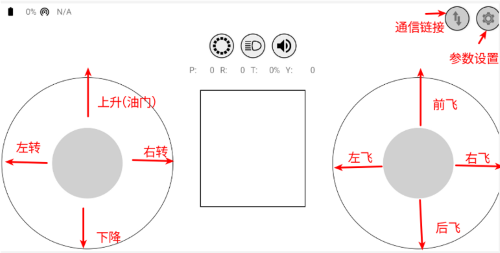
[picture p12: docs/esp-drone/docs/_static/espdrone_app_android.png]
espdrone_app_android
   
</div>

## PC CFClient 使用指引

CFclient 是 `crazeflie` 源工程的上位机，完全实现了 `CRTP` 协议中定义的功能，可以加快飞机的调试过程，ESP-Drone 项目对该上位机进行裁剪和调整，满足功能设计需求。

<div align="center">
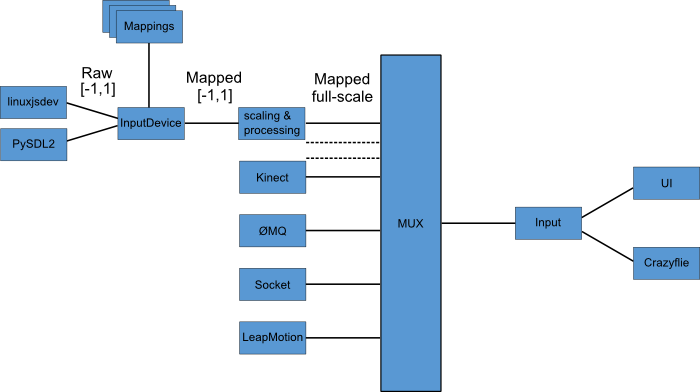
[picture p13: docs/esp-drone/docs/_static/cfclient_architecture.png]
cfclient_architecture
   
</div>

cfclient控制台界面

项目中有很多相关的文件，例如配置文件和缓存文件，其中JSON文件用来存储配置信息。关于配置信息中内容的解读：[User configuration file](https://www.bitcraze.io/docs/crazyflie-clients-python/master/dev_info_client/)

### 飞行设置

**基本飞行设置 Basic Flight Control**

1. 飞行模式 Flight mode selector \(Normal and Advanced\)
   * 基本模式 _Normal: 初学者使用
   * 高级模式 _Advanced: 设置解锁最大角度，设置最大油门。
2. 自动模式 Assisted mode selection. 
   * 定海拔模式 _Altitude hold_: 保持飞行海拔，需要气压计支持。
   * 定点模式 _Position hold_: 保持当前位置，需要光流和TOF支持。 
   * 定高模式 _Height hold_: 保持相对高度, 触发时保持高于地面 40cm ，需要TOF支持。
   * 悬停模式 _Hover : 触发时保持高于地面 40cm，并悬停在起飞点，需要光流和TOF支持。
3. 角度修正 trim
	* Roll Trim : 翻滚角修正，用于弥补传感器水平安装误差
	* Pitch Trim : 俯仰角修正，用于弥补传感器水平安装误差

> 在自动模式下，油门摇杆变为高度控制摇杆

**高级飞行设置 Advanced Flight Control**

1.  最大倾角 _Max angle: 设置最大允许的俯仰和翻滚角度 roll/pitch
2. 最大自选速度 _Max yaw rate: 设置允许的偏航速度  yaw 
3. 最大油门 _Max thrust: 设置最大油门
4. 最小油门 _Min thrust: 设置最小油门
5. 回转极限 _Slew limit:  回转极限。防止油门骤降，油门低于该值时，将被平滑的接管。 Set the percentage where the thrust is slew controlled \(the thrust value lowering will be limited\). This makes the Crazyflie a bit easier to fly for beginners
6. 回转率 _Slew rate: 油门到回转极限时，最大的油门值。When the thrust is below the slew limit, this is the maximum rate of lowering the thrust

**遥控器设置 Configure input device**

按照提示绑定遥控器摇杆与各个控制通道：

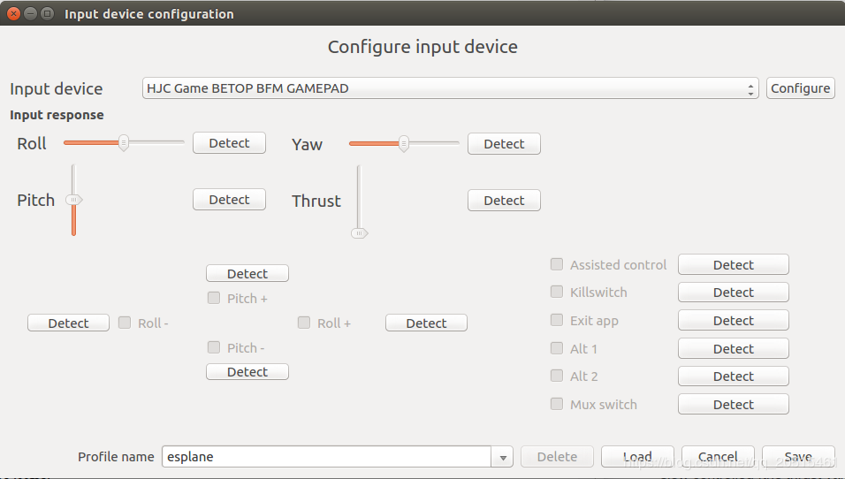
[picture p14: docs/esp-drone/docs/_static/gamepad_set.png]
按照提示绑定遥控器摇杆与各个控制通道


**飞行数据 Fligt Data**

驾驶仪可以看到当前飞机姿态，右下方显示对应的详细数据。
1. 目标角度 Target
2. 测量角度 Actual
3. 当前油门值 Thrust
4. 电机实际输出 M1\M2\M3\M4

### 在线参数修改

**注意事项**

1. 修改的参数实时生效，避免了频繁烧录固件。
2. 可在代码中通过宏定义配置那些参数可被上位机实时修改。
3. 注意参数在线修改仅用于调试，掉电不保存。

**在线调整 PID 参数**

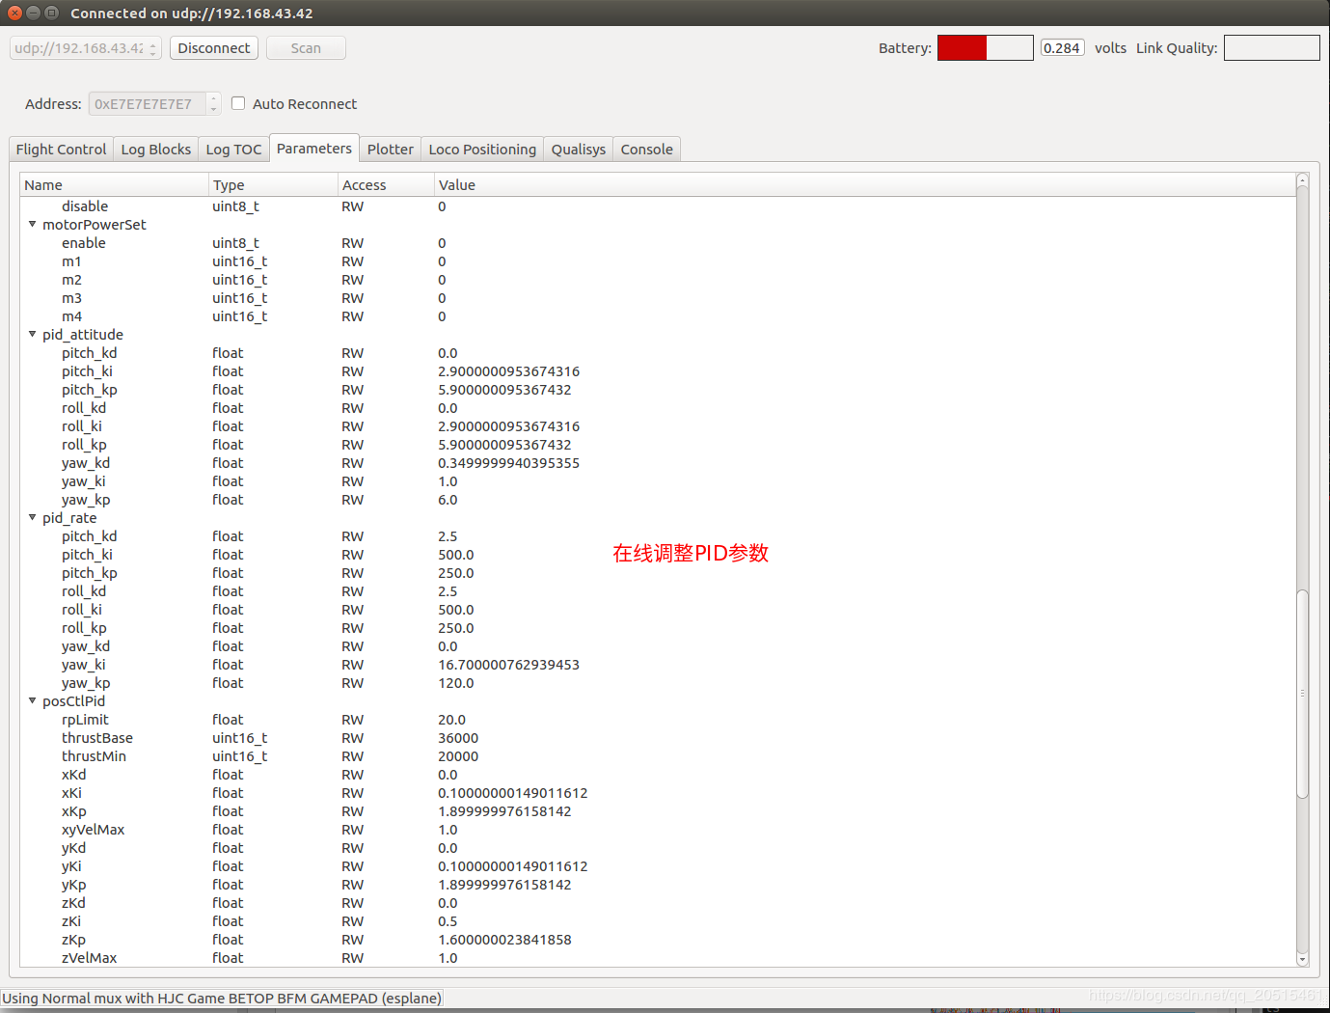
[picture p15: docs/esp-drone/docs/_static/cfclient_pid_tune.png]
cfclient_pid_tune


### 飞行数据监控

**配置要监控的参数**

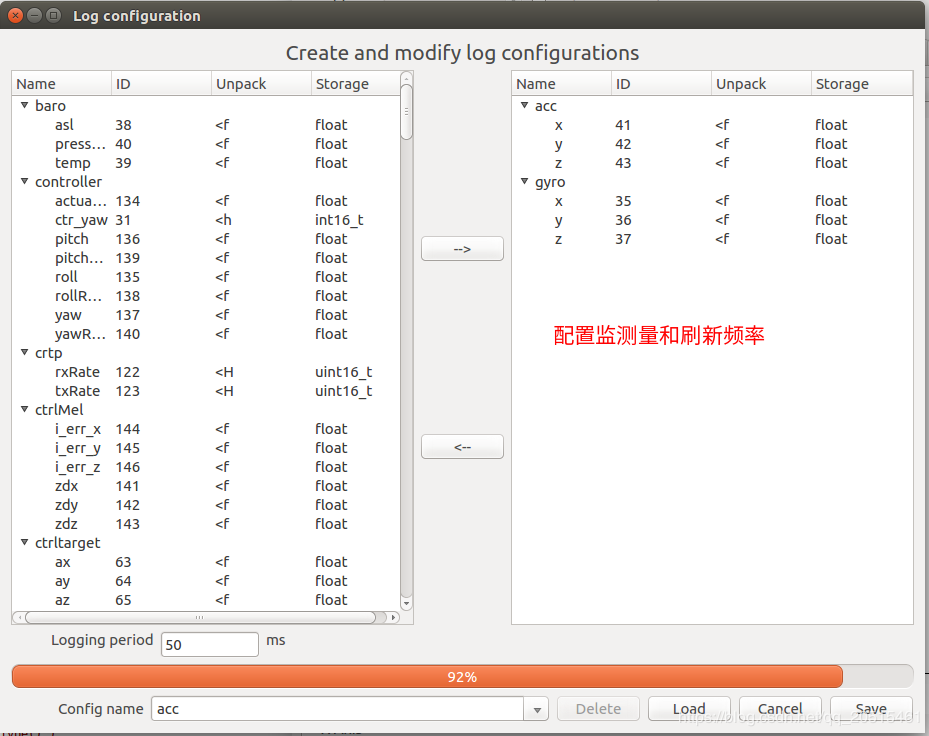
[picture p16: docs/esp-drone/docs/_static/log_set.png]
logging set


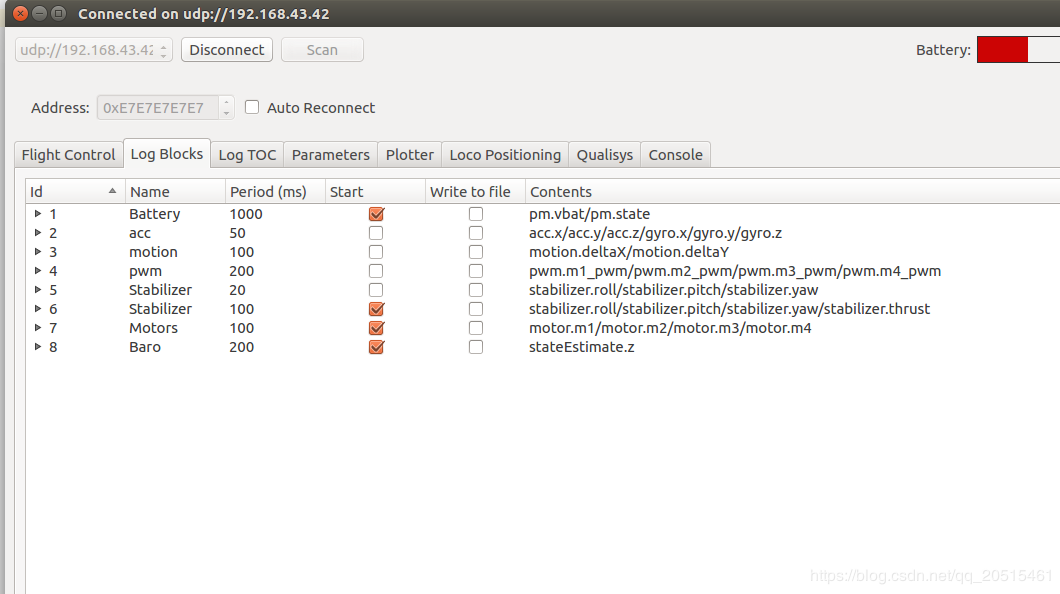
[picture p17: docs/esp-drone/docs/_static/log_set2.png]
logging set2


**实时波形绘制**

陀螺仪加速度计实时数据监测：

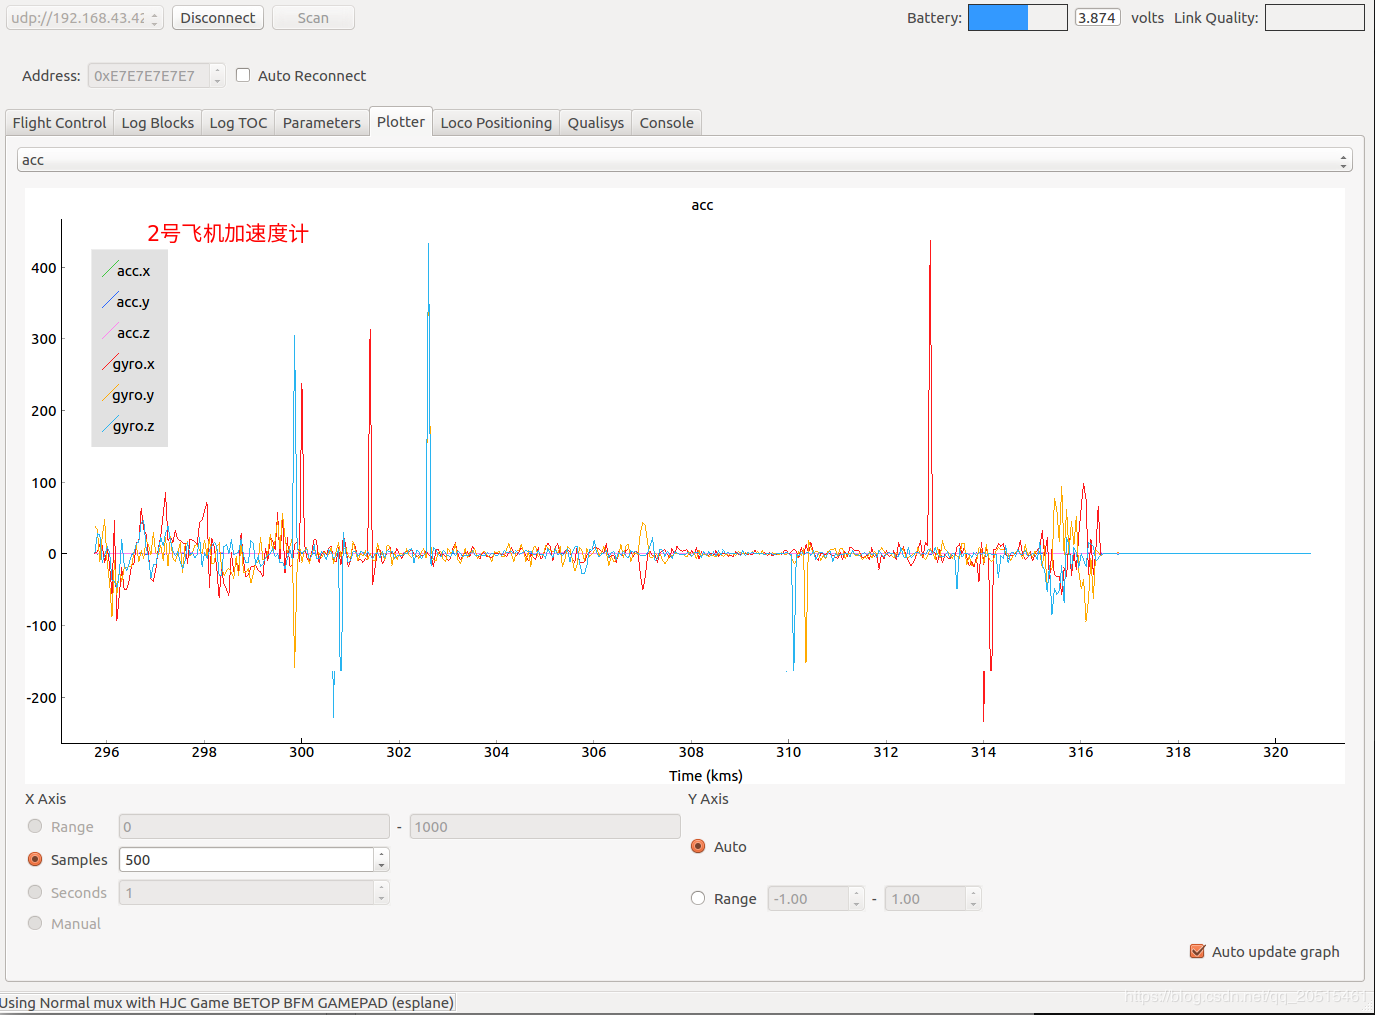
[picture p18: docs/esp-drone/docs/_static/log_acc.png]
logging acc


## 螺旋桨方向

* 注意按照下图所示位置，安装 A B 螺旋桨
* 注意检查飞机上电自检时，螺旋桨转向是否正确？

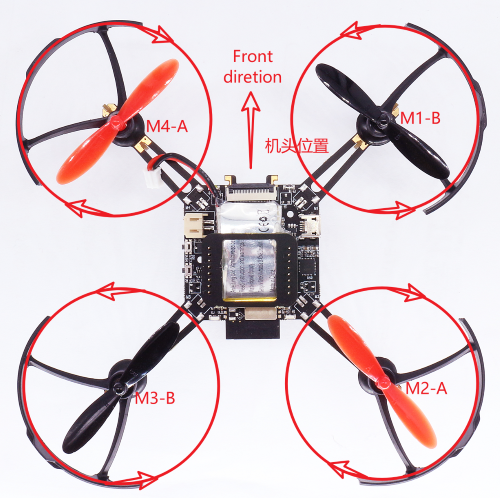
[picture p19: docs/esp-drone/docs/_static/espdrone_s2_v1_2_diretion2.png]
esplane_1_0


## 起飞前检查

* 将飞机头部朝前放置，尾部天线朝向自己
* 注意将飞机置于水平面上，机身稳定时上电
* 注意观察上位机水平面是否置平？
* 注意观察通信建立以后，小飞机尾部绿灯是否快速闪速
* 注意观察小飞机头部红灯是否熄灭，亮起代表电量不足
* 轻推左手小油门，检查飞机是否能快速响应
* 轻推右手方向，检查方向控制是否正确
* 起飞吧！

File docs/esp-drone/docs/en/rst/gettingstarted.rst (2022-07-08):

================
Get Started 
================

:link_to_translation:`zh_CN:[中文]`

ESP-Drone Overview
======================

ESP-Drone is an ESP32/ESP32-S2 based flying development board provided by Espressif. ESP-Drone is equipped with Wi-Fi key features, which allows this drone to be connected to and controlled by an APP or a gamepad over a Wi-Fi network. This drone comes with simple-structured hardware, clear codes, and supports functional extension. Therefore, ESP-Drone can be used in STEAM education. Part of the codes is from Crazyflie open source project under GPL3.0
license.

ESP-Drone
   
   ESP-Drone

Main Features
----------------

ESP-Drone has the following features:

- Stabilize mode: keep the drone stable to achieve smooth flight.
- Height-hold mode: control thrust output to keep the drone flying at a fixed height.
- Position-hold mode: keep the drone flying at a fixed position.
- PC debugging: use cfclient for static/dynamic debugging.
- Controlled by APP: easily controlled over Wi-Fi by your mobile APP.
- Controlled by gamepad: easily controlled via the gamepad by cfclient.

Main Components
----------------

ESP-Drone 2.0 consists of a main board and several extension boards:

-  **Main board**: integrates an ESP32-S2 module, necessary sensors for basic flight, and provides hardware extension interfaces.
-  **Extension boards**: integrate extension sensors via hardware extension interfaces of the main board, to implement advanced flight.  

.. list-table:: 
   :widths: 4 20 15 15 10 10
   :header-rows: 1

   * - No.
     - Modules
     - Main Components
     - Function
     - Interfaces
     - Mount Location
   * - 1
     - Main board - **ESP32-S2**
     - ESP32-S2-WROVER + MPU6050
     - Basic flight
     - I2C, SPI, GPIO, extension interfaces
     - 
   * - 2
     - Extension board - **Position-hold module**
     - PMW3901 + VL53L1X
     - Indoor position-hold flight
     - SPI + I2C
     - Mount at bottom, facing to the ground.
   * - 3
     - Extension board - **Pressure module**
     - MS5611 pressure module
     - Height-hold flight
     - I2C or MPU6050 slave
     - Mount at the top or at the bottom
   * - 4
     - Extension board - **Compass module**
     - HMC5883 compass
     - Advanced flight mode, such as head-free mode
     - I2C or MPU6050 slave
     - Mount at the top or at the bottom

For more information, please refer to `Hardware Reference <./hardware.rst>`__.

ESP-IDF Overview
================

ESP-IDF is the IoT Development Framework provided by Espressif for ESP32/ESP32-S2.

- ESP-IDF is a collection of libraries and header files that provides the core software components that are required to build any software projects on ESP32/ESP32-S2.

- ESP-IDF also provides tools and utilities that are required for typical developer and production use cases, like build, flash, debug and measure. 

For more information, please check `ESP-IDF
Programming Guide <https://docs.espressif.com/projects/esp-idf/zh_CN/latest/esp32s2/get-started/index.html>`__.

Crazyflie Overview
=======================

Crazyflie is a Bitcraze open-source quadcopter, with the following features:

- Support various sensor combinations for advanced flight modes, such as Height-hold mode and Position-hold mode.
- Based on FreeRTOS, which allows users to break down complex drone systems into multiple software tasks with various priorities.
- Customized full-featured cfclient and CRTP communication protocol, for debug, measurement, and control purposes.

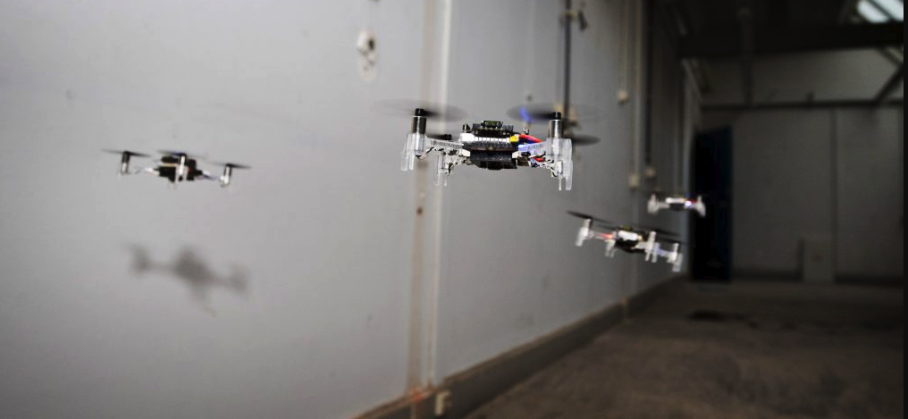
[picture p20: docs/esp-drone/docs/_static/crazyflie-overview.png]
crazyflie-overview

   
   `A swarm of drones exploring the environment, avoiding obstacles
   and each other. (Guus Schoonewille, TU Delft) <https://img-blog.csdnimg.cn/20191030202634944.jpg?x-oss-process=image/watermark,type_ZmFuZ3poZW5naGVpdGk,shadow_10,text_aHR0cHM6Ly9ibG9nLmNzZG4ubmV0L3FxXzIwNTE1NDYx,size_16,color_FFFFFF,t_70>`__

For more information, see `Crazyflie <https://www.bitcraze.io/>`__.

Preparations
================

Assemble Hardware
--------------------

Please follow the steps below to assemble ESP32-S2-Drone V1.2.

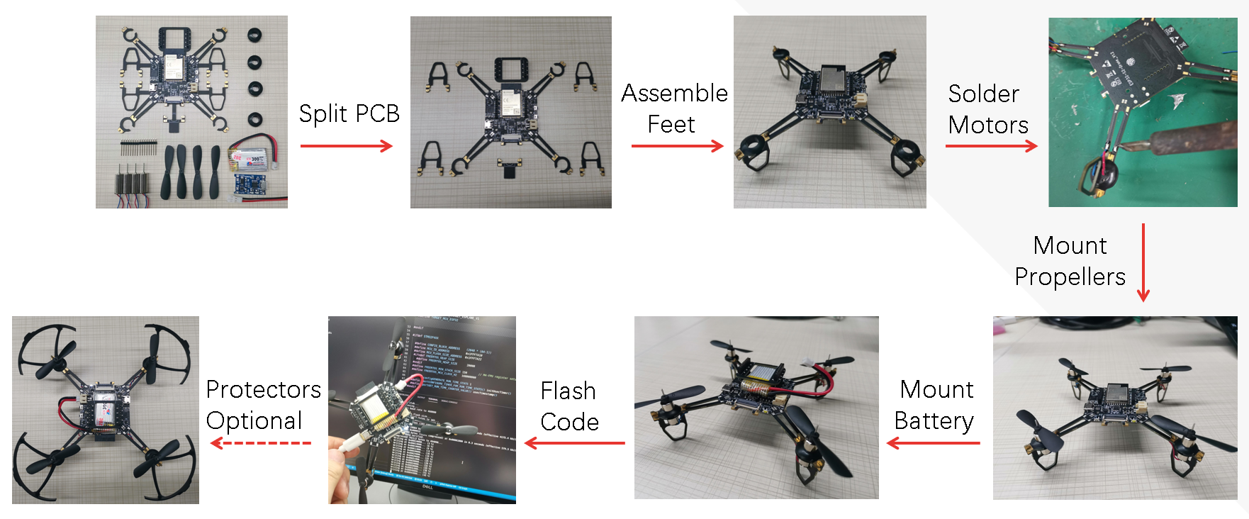
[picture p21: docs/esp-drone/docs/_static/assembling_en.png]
ESP32-S2-Drone V1.2 Assemble Flow

   
   ESP32-S2-Drone V1.2 Assemble Flow

Hardware overview and pin allocation are available at: `Hardware Reference <./hardware.rst>`__.

Download and Install ESP-Drone APP
----------------------------------------
ESP-Drone APP is available for Android and iOS.

For Android, please scan the QR below to download ESP-Drone APP.

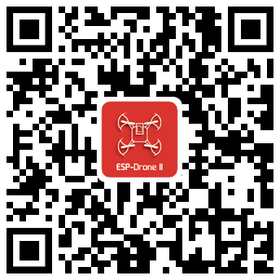
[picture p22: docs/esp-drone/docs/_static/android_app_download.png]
Android APP QR


For iOS, please search and download the ESP-Drone APP in App Store.

iOS APP source code:
`ESP-Drone-iOS <https://github.com/EspressifApps/ESP-Drone-iOS>`__

Android APP source code:
`ESP-Drone-Android <https://github.com/EspressifApps/ESP-Drone-Android>`__

Install cfclient
--------------------

This step is optional, only for advanced debugging.

cfclient Interface

   cfclient Interface

**1. Install CRTP protocol package**

1.1 Download the source code

.. code:: text

   git clone -b esp-drone  https://github.com/qljz1993/crazyflie-lib-python.git

1.2 Navigate to the source code directory, and install the requirements

.. code:: text

   pip3 install -r requirements.txt

1.3 Install CRTP package

.. code:: text

   pip3 install -e .

**2. Install cfclient**

2.1 Download the source code

.. code:: text

   git clone -b esp-drone https://github.com/qljz1993/crazyflie-clients-python.git

2.2 Navigate to the source code directory, and install the requirements

.. code:: text

   sudo apt-get install python3 python3-pip python3-pyqt5 python3-pyqt5.qtsvg

2.3 Install cfclient

.. code:: text

   pip3 install -e .

2.4 Start cfclient

.. code:: text

   python3 ./bin/cfclient

**3. Configure the controllers**

Controller Configuration

   Controller Configuration

3.1 Configure the four main dimensions of controls: ``Roll, Pitch, Yaw, Thrust``.

3.2 Configure button ``Assisted control`` for flight mode switching.

ESP-Drone APP Guide
=====================

Establish Wi-Fi connection
---------------------------
* Scan Wi-Fi AP on your mobile. ESP-Drone device works as a Wi-Fi AP with the following SSID:  

::

   SSID: ESP-DRONE_XXXX (XXXX is configured based on MAC) PASSWORD: 12345678

* Click this AP, connect your mobile to this AP.

Now a Wi-Fi connection is established between your mobile and your drone.

Customize settings
---------------------------
In this step, you can customize the flight settings according to your application scenarios, or use the default configuration below.

::

   ```
   Default configuration:

   Flight control settings 
       1. Mode: Mode2
       2. Deadzone: 0.2
       3. Roll trim: 0.0
       4. Pitch trim: 0.0
       5. Advanced flight control: true
       6. Advanced flight control preferences 
           1. max roll/pitch angle: 15
           2. max yaw angle: 90
           3. max thrust: 90
           4. min thrust: 25
           5. X-Mode: true
   Controller settings 
       1. use full travel for thrust: false
       2. virtual joystick size: 100
   App settings
       1. Screen rotation lock: true
       2. full screen mode:true
       3. show console: true   
   ```

Flight Control
---------------------

- Click “Connect” button/icon at your APP. When the connection is established successfully between your drone and APP, the LED on the drone blinks GREEN.
- Slide “Thrust” slightly to take off the drone.
- Control the flight by moving your fingers on the APP.

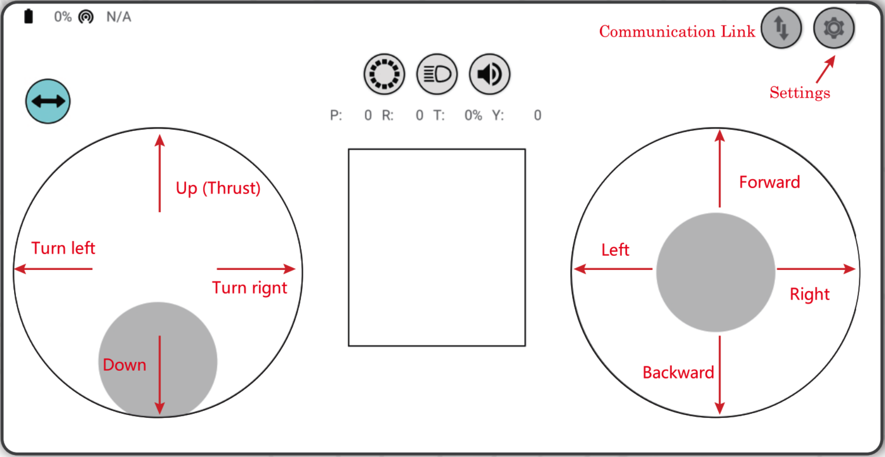
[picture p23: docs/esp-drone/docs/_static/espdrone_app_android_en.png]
Android APP Interface


   Android APP Interface

PC cfclient Guide
======================

Cfclient is the PC client for ``Crazeflie`` source project, which has fully implemented the functions defined in ``CRTP`` and makes the drone debugging faster. ESP-Drone customizes this cfclient to meet functional design needs.

cfclient architecture

   Cfclient Architecture

cfclient console interface

   Cfclient Console Interface

In this project, we have configuration files and cache files. JSON file is used to store configuration information. For more information about the configuration, please refer to `User
Configuration File <https://www.bitcraze.io/documentation/repository/crazyflie-clients-python/master/development/dev_info_client/>`__.

Flight Settings
--------------------

Basic Flight Control
~~~~~~~~~~~~~~~~~~~~~~

1. Flight mode: normal and advanced modes

   - Normal mode: for beginners.
   - Advanced mode: unlock the maximum angle and the maximum thrust.

2. Assisted mode

   - Altitude-hold mode: maintain flight altitude. To implement this mode, a barometric pressure sensor is needed.
   - Position-hold mode: maintain current flight position. To implement this mode, an optical flow sensor and a Time of Flight (TOF) sensor are needed.
   - Height-hold mode: keep flight height. Note: to apply this mode, the drone should fly at 40 cm or higher over the ground, and a TOF is needed.
   - Hover mode: stay and hover at 40 cm or higher over the take-off point. To implement this mode, a optical flow sensor and a TOF are needed.

3. Trim

   - Roll Trim: trim the rotation around a horizontal axis going through the drone from back to front. This rotation literally rolls the drone and moves it left and right. Roll trim is used to compensate for the level installation deviation of sensors.
   - Pitch Trim: trim the rotation around a horizontal axis going through the drone from left to right. This rotation tilts the drone and moves it forwards or backwards. Pitch trim is used to compensate for the level installation deviation of sensors.

Note that in assisted mode, the thrust controller works as a height controller.

Advanced Flight Control
~~~~~~~~~~~~~~~~~~~~~~~~

1. Max angle: set the maximum pitch and roll rotation: roll/pitch.
2. Max yaw rate: set the allowed yaw: ``yaw``.
3. Max thrust: set the maximum thrust.
4. Min thrust: set the minimum thrust.
5. Slew limit: prevent sudden drop of thrust. When the thrust drops below this limit, the rates below ``Slew rate`` will not be allowed.
6. Slew rate: this is the maximum rate when the thrust is below ``slew limit``.

Configure Input Device
~~~~~~~~~~~~~~~~~~~~~~~~~~~~~

Follow the prompts, route the controllers to each channel.

cfclient input device configuration

   Cfclient Input Device Configuration

Flight Data
~~~~~~~~~~~~~~~~

On the tab “Flight Control” of cfclient, you can check the drone status. The detailed information is shown at the bottom right, including:

1. Target: target angle
2. Actual: measured angle
3. Thrust: current thrust value
4. M1/M2/M3/M4: actual output of motors

Tune Online Parameters
--------------------------

**Tune PID parameters online**

PID parameters tunning
   
   Cfclient PID Parameters Tunning

**Note**

1. The modified parameters take effect in real time, which avoids frequent flash of firmware.
2. You can define in your code which parameters can be modified by PC in real time.
3. Note that modifying parameters online is only for debugging purpose. The modified parameters will not be saved at power down.

Monitor Flight Data
-----------------------

Configure the parameters to monitor at Tab Log configuration and Tab Log Blocks:

Log configuration
   
   Log Configuration

Log Blocks
   
   Log Blocks

Configure real-time waveform drawing at Tab Plotter, to monitor gyro accelerometer data.

accelerometer logging

   Accelerometer Logging

Propeller Direction
=======================

- Install A and B propellers according to the figure below.
- During the power-on self-test, check if the propellers spin properly.

Propeller check

   Propeller Check

Preflight Check
================

- Place the drone with its head on the front, and its tail (i.e. the antenna part) at the back.
- Place the drone on a level surface and power it up when the drone stays still.
- Check on the cfclient if the drone is placed level.
- After the communication is established, check if the LED at the drone tail blinks GREEN fast.
- Check if the LED on the drone head blinks RED, which indicates battery LOW.
- Slide forward the Trust controller slightly at the left side of your APP (i.e. the commands controlled by your left finger), to check if the drone can respond the command quickly.
- Move your finger at the right command area of the APP (i.e. the commands controlled by your right finger), to check if the direction control works well.
- Go fly and have fun!

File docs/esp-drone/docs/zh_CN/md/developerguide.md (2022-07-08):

# 开发指引

* [环境搭建](./getespidf.md) 
    * [ESP-IDF 环境搭建](getespidf.html#esp-idf) 
    * [ESP32/ESP32-S2 链接脚本修改](getespidf.html#esp32-s2)
    * [获取项目源代码](getespidf.html#id2)
* [驱动程序](./drivers.md)
    * [通用设备](drivers.html#generall)
    * [I2C 总线设备](drivers.html#i2c-devices)
    * [SPI 总线设备](drivers.html#spi-devices)
* [飞控系统](./system.md)
    * [系统启动流程](system.html#id2)
    * [系统任务管理](system.html#id3)
    * [关键任务介绍](system.html#id7)
    * [传感器硬件抽象](system.html#id9)
    * [传感器校准](system.html#id10)
    * [姿态计算](system.html#id15)
    * [控制算法](system.html#id19)
* [通信协议](./communication.md)
    * [通信层级结构](communication.html#id2)
    * [Wi-Fi 通信](communication.html#wi-fi)
    * [UDP 通信](communication.html#udp)
    * [CRTP 协议](communication.html#crtp)
    * [基于 CRTP 协议的应用开发](communication.html#id10)

* [硬件参考](./hardware.md)
    * [已支持硬件列表](hardware.html#id3)
    * [ESP32_S2_Drone_V1_2](hardware.html#esp32-s2-drone-v1-2)
    * [ESPlane_V2_S2](hardware.html#esplane-v2-s2)
    * [ESPlane FC V1](hardware.html#esplane-fc-v1)

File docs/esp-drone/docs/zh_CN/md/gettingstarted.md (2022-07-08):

# 快速入门

## 项目简介

ESP-Drone 是基于乐鑫 ESP32/ESP32-S2 开发的小型无人机解决方案，可使用手机 APP 或游戏手柄通过 Wi-Fi 网络进行连接和控制。目前已支持自稳定飞行、定高飞行、定点飞行等多种模式。该方案硬件结构简单，代码架构清晰，支持功能扩展，可用于 STEAM 教育等领域。项目部分代码来自 Crazyflie 开源工程，继承 GPL3.0 开源协议。

ESP-Drone

* 支持自稳定模式 (Stabilize mode)：自动控制机身水平，保持平稳飞行。
* 支持定高模式 (Height-hold mode)：自动控制油门输出，保持固定高度。
* 支持定点模式 (Position-hold mode)：自动控制机身角度，保持固定空间位置。
* 支持 PC 上位机调试：使用 cfclient 上位机进行静态/动态调试。
* 支持 APP 控制：使用手机 APP 通过 Wi-Fi 轻松控制。
* 支持游戏手柄 (gamepad) 控制：通过 cfclient 使用游戏手柄轻松控制。

**ESP-Drone 2.0 使用模块化的设计思路，由主控板和扩展板组成：**

* **主控制板**：搭载 ESP32-S2 模组和支持基础飞行的必要传感器，并提供硬件扩展接口。
* **扩展板**：搭载扩展传感器，可对接主控制板的硬件扩展接口，支持高级飞行功能。

|序号| 模块名 | 主要元器件 | 功能 | 接口 |安装位置 |
|--|--|--|--|--|--|
|1| 主控制板 - **ESP32-S2** |  ESP32-S2-WROVER + MPU6050| 基础飞行 |提供 I2C SPI GPIO 扩展接口  ||
|2|扩展板 - **定点模块** |  PMW3901 + VL53L1X | 室内定点飞行 | SPI + I2C | 底部，面向地面 |
|3| 扩展板 - **气压定高模块** |  MS5611 气压 | 气压定高 | I2C 或 MPU6050 从机|顶部或底部 |
|4| 扩展板 - **指南针模块** |  HMC5883 罗盘 | 无头模式等高级模式 | I2C 或 MPU6050 从机|顶部或底部 |

详情可查阅：[硬件参考](./hardware.md)。

## ESP-IDF 简介

ESP-IDF 是乐鑫为 ESP32/ESP32-S2 提供的物联网开发框架。

* ESP-IDF 包含一系列库及头文件，提供了基于 ESP32/ESP32-S2 构建软件项目所需的核心组件。
* ESP-IDF 还提供了开发和量产过程中最常用的工具及功能，例如：构建、烧录、调试和测量等。

详情可查阅：[ESP-IDF 编程指南](https://docs.espressif.com/projects/esp-idf/zh_CN/latest/esp32s2/get-started/index.html)。

## Crazyflie 简介

Crazyflie 是来自 Bitcraze 开源工程的四旋翼飞行器，具备以下特性：

* 支持多种传感器组合，可以轻松实现定高模式、定点模式等高级飞行模式。
* 基于 FreeRTOS 编写，将复杂的无人机系统，分解成多个具有不同优先级的软件任务。
* 设计了功能完备的 cfclient 上位机和 CRTP 通信协议，便于实现调试、测量和控制。

A swarm of drones exploring the environment, avoiding obstacles and each other. \(Guus Schoonewille, TU Delft\)

>图片介绍：多架无人机同时探索周围环境，灵活避开障碍物，同时避开其它无人机。[A swarm of drones exploring the environment, avoiding obstacles and each other. \(Guus Schoonewille, TU Delft\)](https://img-blog.csdnimg.cn/20191030202634944.jpg?x-oss-process=image/watermark,type_ZmFuZ3poZW5naGVpdGk,shadow_10,text_aHR0cHM6Ly9ibG9nLmNzZG4ubmV0L3FxXzIwNTE1NDYx,size_16,color_FFFFFF,t_70)

详情可查阅 [Crazyflie 官网](https://www.bitcraze.io/)。

## 准备工作

### 硬件组装

ESP32-S2-Drone V1.2：

assembling

硬件介绍和管脚资源分配可查阅：[硬件参考](./hardware.md)。

### 安装 ESP-Drone APP

**Android APP 扫码下载：**

<div align="center">
   android_app_download
</div>

**iOS APP 下载**

苹果 App Store 搜索 `ESPDrone`，下载并安装。

**iOS APP 源代码**: [ESP-Drone-iOS](https://github.com/EspressifApps/ESP-Drone-iOS)

**Android APP 源代码**: [ESP-Drone-Android](https://github.com/EspressifApps/ESP-Drone-Android)

### 安装 cfclient

安装 cfclient 为可选步骤，用于实现高级调试，非必须使用。

cfclient

**1. 安装 CRTP 协议支持包**

1.1 下载源代码 

```text
git clone -b esp-drone  https://github.com/qljz1993/crazyflie-lib-python.git
```

1.2 进入源码目录，安装依赖 

```text
pip3 install -r requirements.txt
```

1.3 安装 CRTP 包 

```text
pip3 install -e .
```

**2. 安装 cfclient**

2.1 下载源代码

```text
git clone -b esp-drone https://github.com/qljz1993/crazyflie-clients-python.git
```

2.2  进入源码目录，安装依赖 

```text
sudo apt-get install python3 python3-pip python3-pyqt5 python3-pyqt5.qtsvg
```

2.3  安装 cfclient 客户端

```text
pip3 install -e .
```

2.4 启动客户端

```text
python3 ./bin/cfclient
```

**3. 配置遥控器**

gamepad_settings

3.1 配置 4 个控制轴：`Roll 、Pitch、Yaw、Thrust`。

3.2 配置一个按键为 `Assisted control`，用于飞行模式切换。

## 手机 APP 使用指引

１. Wi-Fi 连接

    SSID：ESPDRONE_XXXX（XXXX 根据 MAC 设置）PASSWORD：12345678

２. 个性化设置

	```
	默认配置：

	Flight control settings 
		1. Mode: Mode2
		2. Deadzone: 0.2
		3. Roll trim: 0.0
		4. Pitch trim: 0.0
		5. Advanced flight control : true
		6. Advanced flight control preferences 
			1. max roll/pitch angle: 15
			2. max yaw angle: 90
			3. max thrust: 90
			4. min thrust: 25
			5. X-Mode: true
	Controller settings 
		1. use full travel for thrust: false
		2. virtual joystick size: 100
	App settings
		1. Screen rotation lock: true
		2. full screen mode:true
		3. show console: true   
	```

３. 控制飞行

* 打开通信连接，小飞机绿灯将闪烁。
* 轻推油门，起飞。

<div align="center">
   espdrone_app_android
</div>

## PC cfclient 使用指南

cfclient 是 `Crazeflie` 源工程的上位机，完全实现了 `CRTP` 协议中定义的功能，可以加快飞机的调试过程。ESP-Drone 项目对该上位机进行裁剪和调整，满足功能设计需求。

<div align="center">
   cfclient_architecture
</div>

cfclient控制台界面

项目中有很多相关的文件，例如配置文件和缓存文件，其中 JSON 文件用来存储配置信息。关于配置信息中内容的解读，可参考：[User Configuration File](https://www.bitcraze.io/documentation/repository/crazyflie-clients-python/master/development/dev_info_client/)。

### 飞行设置

**基本飞行设置 (Basic Flight Control)**

1. 飞行模式 (Flight mode)：基本模式和高级模式
   * 基本模式 (Normal mode)：初学者使用。
   * 高级模式 (Advanced mode)：设置解锁最大角度，设置最大油门。
2. 自动模式 (Assisted mode) 
   * 定海拔模式 (Altitude-hold mode)：保持飞行海拔，需要气压计支持。
   * 定点模式 (Position-hold mode)：保持当前位置，需要光流和 TOF 支持。 
   * 定高模式 (Height-hold mode)：保持相对高度，触发时保持高于地面 40 cm，需要 TOF 支持。
   * 悬停模式 (Hover mode)：触发时保持高于地面 40 cm，并悬停在起飞点，需要光流和 TOF 支持。
3. 角度修正 (Trim)
	* 翻滚角修正 (Roll Trim)：用于弥补传感器水平安装误差。
	* 俯仰角修正 (Pitch Trim)：用于弥补传感器水平安装误差。

注意，在自动模式下，油门摇杆变为高度控制摇杆。

**高级飞行设置 (Advanced Flight Control)**

1. 最大倾角 (Max angle)：设置最大允许的俯仰和翻滚角度：roll/pitch。
2. 最大自选速度 (Max yaw rate)：设置允许的偏航速度：yaw。 
3. 最大油门 (Max thrust)：设置最大油门。
4. 最小油门 (Min thrust)：设置最小油门。
5. 回转极限 (Slew limit)：回转极限。防止油门骤降，油门低于该值时，将被平滑的接管。
6. 回转率 (Slew rate)：油门到回转极限时，最大的油门值。

**遥控器设置 (Configure Input Device)**

按照提示绑定遥控器摇杆与各个控制通道：

按照提示绑定遥控器摇杆与各个控制通道

**飞行数据 (Flight Data)**

驾驶仪可以看到当前飞机姿态，右下方显示对应的详细数据。

1. 目标角度 (Target)
2. 测量角度 (Actual)
3. 当前油门值 (Thrust)
4. 电机实际输出 (M1/M2/M3/M4)

### 在线参数修改

**注意事项**

1. 修改的参数实时生效，避免了频繁烧录固件。
2. 可在代码中通过宏定义，配置哪些参数可被上位机实时修改。
3. 注意，参数在线修改仅用于调试，掉电不保存。

**在线调整 PID 参数**

cfclient_pid_tune

### 飞行数据监控

**配置要监控的参数**

logging set

logging set2

**实时波形绘制**

陀螺仪加速度计实时数据监测：

logging acc

## 螺旋桨方向

* 按照下图所示位置，安装 A、B 螺旋桨。
* 飞行器上电自检时，检查螺旋桨转向是否正确。

esplane_1_0

## 起飞前检查

* 将飞机头部朝前放置，尾部天线朝向自己。
* 将飞机置于水平面上，待机身稳定时上电。
* 观察上位机水平面是否置平。
* 观察通信建立以后，小飞机尾部绿灯是否快速闪烁。
* 观察小飞机头部红灯是否熄灭，亮起代表电量不足。
* 轻推左手小油门，检查飞机是否能快速响应。
* 轻推右手方向，检查方向控制是否正确。
* 起飞吧！

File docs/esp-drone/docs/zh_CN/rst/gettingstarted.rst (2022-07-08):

========
快速入门
========

:link_to_translation:`en:[English]`

项目简介
========

ESP-Drone 是基于乐鑫 ESP32/ESP32-S2 开发的小型无人机解决方案，可使用手机 APP 或游戏手柄通过 Wi-Fi
网络进行连接和控制。该方案硬件结构简单，代码架构清晰，支持功能扩展，可用于
STEAM 教育等领域。项目部分代码来自 Crazyflie 开源工程，继承 GPL3.0
开源协议。

ESP-Drone 无人机
   
   ESP-Drone 无人机

主要特性
---------

ESP-Drone 具备以下特性：

-  支持自稳定模式 (Stabilize mode)：自动控制机身水平，保持平稳飞行。
-  支持定高模式 (Height-hold mode)：自动控制油门输出，保持固定高度。
-  支持定点模式 (Position-hold mode)：自动控制机身角度，保持固定空间位置。
-  支持 PC 上位机调试：使用 cfclient 上位机进行静态/动态调试。
-  支持 APP 控制：使用手机 APP 通过 Wi-Fi 轻松控制。
-  支持游戏手柄 (gamepad) 控制：通过 cfclient 使用游戏手柄轻松控制。

主要组件
----------------

ESP-Drone 2.0 使用模块化的设计思路，由主控板和扩展板组成。

-  **主控制板**：搭载 ESP32-S2 模组和支持基础飞行的必要传感器，并提供硬件扩展接口。
-  **扩展板**：搭载扩展传感器，可对接主控制板的硬件扩展接口，支持高级飞行功能。

==== ========================= ========================= ================== ========================== ==============
序号 模块名                    主要元器件                功能               接口                       安装位置
==== ========================= ========================= ================== ========================== ==============
1    主控制板 - **ESP32-S2**   ESP32-S2-WROVER + MPU6050 基础飞行           提供 I2C SPI GPIO 扩展接口
2    扩展板 - **定点模块**     PMW3901 + VL53L1X         室内定点飞行       SPI + I2C                  底部，面向地面
3    扩展板 - **气压定高模块** MS5611 气压               气压定高           I2C 或 MPU6050 从机        顶部或底部
4    扩展板 - **指南针模块**   HMC5883 罗盘              无头模式等高级模式 I2C 或 MPU6050 从机        顶部或底部
==== ========================= ========================= ================== ========================== ==============

详情可查阅：`硬件参考 <./hardware.rst>`__。

ESP-IDF 简介
================

ESP-IDF 是乐鑫为 ESP32/ESP32-S2 提供的物联网开发框架。

-  ESP-IDF 包含一系列库及头文件，提供了基于 ESP32/ESP32-S2 构建软件项目所需的核心组件。
-  ESP-IDF 还提供了开发和量产过程中最常用的工具及功能，例如：构建、烧录、调试和测量等。

详情可查阅：`ESP-IDF 编程指南 <https://docs.espressif.com/projects/esp-idf/zh_CN/latest/esp32s2/get-started/index.html>`__。

Crazyflie 简介
================

Crazyflie 是来自 Bitcraze 开源工程的四旋翼飞行器，具备以下特性：

-  支持多种传感器组合，可以轻松实现定高模式、定点模式等高级飞行模式。
-  基于 FreeRTOS 编写，将复杂的无人机系统，分解成多个具有不同优先级的软件任务。
-  设计了功能完备的 cfclient 上位机和 CRTP 通信协议，便于实现调试、测量和控制。

crazyflie-overview

   多架无人机同时探索周围环境，灵活避开障碍物，同时避开其它无人机。\ `A
   swarm of drones exploring the environment, avoiding obstacles and
   each other. (Guus Schoonewille, TU
   Delft) <https://img-blog.csdnimg.cn/20191030202634944.jpg?x-oss-process=image/watermark,type_ZmFuZ3poZW5naGVpdGk,shadow_10,text_aHR0cHM6Ly9ibG9nLmNzZG4ubmV0L3FxXzIwNTE1NDYx,size_16,color_FFFFFF,t_70>`__

详情可查阅 `Crazyflie 官网 <https://www.bitcraze.io/>`__。

准备工作
================

硬件组装
----------

请按照下述步骤组装 ESP32-S2-Drone V1.2：

ESP32-S2-Drone V1.2 组装流程
   
   ESP32-S2-Drone V1.2 组装流程

硬件介绍和管脚资源分配可查阅：`硬件参考 <./hardware.rst>`__。

安装 ESP-Drone APP
--------------------

ESP-Drone APP 同时支持 Android 系统和 iOS 系统。

**扫描下方二维码，下载 Android APP：**

Android APP 扫码下载

**下载 iOS APP：**

在 App Store 中搜索 ESP-Drone，点击下载并安装。

**iOS APP 源代码**：`ESP-Drone-iOS <https://github.com/EspressifApps/ESP-Drone-iOS>`__

**Android APP 源代码**：`ESP-Drone-Android <https://github.com/EspressifApps/ESP-Drone-Android>`__

安装 cfclient
--------------------

安装 cfclient 为可选步骤，用于实现高级调试，非必须使用。

cfclient 上位机界面

   cfclient 上位机界面

**1. 安装 CRTP 协议支持包**

1.1 下载源代码

.. code:: text

   git clone -b esp-drone  https://github.com/qljz1993/crazyflie-lib-python.git

1.2 进入源码目录，安装依赖

.. code:: text

   pip3 install -r requirements.txt

1.3 安装 CRTP 包

.. code:: text

   pip3 install -e .

**2. 安装 cfclient**

2.1 下载源代码

.. code:: text

   git clone -b esp-drone https://github.com/qljz1993/crazyflie-clients-python.git

2.2 进入源码目录，安装依赖

.. code:: text

   sudo apt-get install python3 python3-pip python3-pyqt5 python3-pyqt5.qtsvg

2.3 安装 cfclient 客户端

.. code:: text

   pip3 install -e .

2.4 启动客户端

.. code:: text

   python3 ./bin/cfclient

**3. 配置遥控器**

游戏手柄配置

   遥控器配置

3.1 配置 4 个控制轴：``Roll 、Pitch、Yaw、Thrust``。

3.2 配置一个按键为 ``Assisted control``，用于飞行模式切换。

手机 APP 使用指南
========================

Wi-Fi 连接
---------------------------
* 手机扫描 Wi-Fi AP。ESP-Drone 设备用作 AP，其 SSID 及密码如下：

::

   SSID：ESP-DRONE_XXXX（XXXX 根据 MAC 设置）PASSWORD：12345678

* 点击该 AP，手机与 ESP-Drone 设备建立 Wi-Fi 连接。

个性化设置
-----------

在该步骤中，您可以按照具体的应用场景进行个性化配置，或使用默认配置。

::

   ```
   默认配置：

   Flight control settings 
       1. Mode: Mode2
       2. Deadzone: 0.2
       3. Roll trim: 0.0
       4. Pitch trim: 0.0
       5. Advanced flight control : true
       6. Advanced flight control preferences 
           1. max roll/pitch angle: 15
           2. max yaw angle: 90
           3. max thrust: 90
           4. min thrust: 25
           5. X-Mode: true
   Controller settings 
       1. use full travel for thrust: false
       2. virtual joystick size: 100
   App settings
       1. Screen rotation lock: true
       2. full screen mode:true
       3. show console: true   
   ```

控制飞行
--------

-  打开 APP，点击 `Connect` 按钮，连接小飞机。连接成功，小飞机绿灯闪烁。
-  轻推油门，小飞机起飞。
-  在 APP 上滑动，控制小飞机方向。

Android APP 用户界面

   Android APP 用户界面

PC cfclient 使用指南
========================

cfclient 是 ``Crazeflie`` 源工程的上位机，完全实现了 ``CRTP``
协议中定义的功能，可以加快飞机的调试过程。ESP-Drone
项目对该上位机进行裁剪和调整，满足功能设计需求。

cfclient 架构

   cfclient 架构

cfclient 控制台界面

   cfclient 控制台界面

项目中有很多相关的文件，例如配置文件和缓存文件，其中 JSON
文件用来存储配置信息。关于配置信息中内容的解读，可参考：`User
Configuration
File <https://www.bitcraze.io/documentation/repository/crazyflie-clients-python/master/development/dev_info_client/>`__。

飞行设置
----------

基本飞行设置 (Basic Flight Control)
~~~~~~~~~~~~~~~~~~~~~~~~~~~~~~~~~~~~~

1. 飞行模式 (Flight mode)：基本模式和高级模式

   -  基本模式 (Normal mode)：初学者使用。
   -  高级模式 (Advanced mode)：设置解锁最大角度，设置最大油门。

2. 自动模式 (Assisted mode)

   -  定海拔模式 (Altitude-hold mode)：保持飞行海拔，需要气压计支持。
   -  定点模式 (Position-hold mode)：保持当前位置，需要光流和 TOF 支持。
   -  定高模式 (Height-hold mode)：保持相对高度，触发时保持高于地面 40
      cm，需要 TOF 支持。
   -  悬停模式 (Hover mode)：触发时保持高于地面 40
      cm，并悬停在起飞点，需要光流和 TOF 支持。

3. 角度修正 (Trim)

   -  翻滚角修正 (Roll Trim)：用于弥补传感器水平安装误差。
   -  俯仰角修正 (Pitch Trim)：用于弥补传感器水平安装误差。

注意，在自动模式下，油门摇杆变为高度控制摇杆。

高级飞行设置 (Advanced Flight Control)
~~~~~~~~~~~~~~~~~~~~~~~~~~~~~~~~~~~~~~

1. 最大倾角 (Max angle)：设置最大允许的俯仰和翻滚角度：roll/pitch。
2. 最大自旋速度 (Max yaw rate)：设置允许的偏航速度：yaw。
3. 最大油门 (Max thrust)：设置最大油门。
4. 最小油门 (Min thrust)：设置最小油门。
5. 压摆极限 (Slew limit)：防止油门骤降，油门低于该值时，下降速度将被限定。
6. 压摆率 (Slew rate)：油门到压摆极限之后的最大下降率。

遥控器设置 (Configure Input Device)
~~~~~~~~~~~~~~~~~~~~~~~~~~~~~~~~~~~~~~

按照提示绑定遥控器摇杆与各个控制通道：

cfclient 控制器配置

飞行数据 (Flight Data)
~~~~~~~~~~~~~~~~~~~~~~~~~~

驾驶仪可以看到当前飞机姿态，右下方显示对应的详细数据。

1. 目标角度 (Target)
2. 测量角度 (Actual)
3. 当前油门值 (Thrust)
4. 电机实际输出 (M1/M2/M3/M4)

在线参数修改
--------------------

**在线调整 PID 参数**

PID 参数调整
   
   cfclient PID 参数调整

**注意事项**

1. 修改的参数实时生效，避免了频繁烧录固件。
2. 可在代码中通过宏定义，配置哪些参数可被上位机实时修改。
3. 注意，参数在线修改仅用于调试，掉电不保存。

飞行数据监控
--------------------

**配置要监控的参数**

PID 参数调整

   监控参数配置

PID 参数调整

   参数配置区

**实时波形绘制**

陀螺仪加速度计实时数据监测：

PID 参数调整

   陀螺仪加速度计数据监测

螺旋桨方向
================

-  按照下图所示位置，安装 A、B 螺旋桨。
-  飞行器上电自检时，检查螺旋桨转向是否正确。

螺旋桨方向示图

   螺旋桨方向示图

起飞前检查
================

-  将小飞机头部朝前放置，尾部天线朝向自己；
-  将小飞机置于水平面上，待机身稳定时上电；
-  观察上位机水平面是否置平；
-  观察通信建立以后，小飞机尾部绿灯是否快速闪烁；
-  观察小飞机头部红灯是否熄灭，亮起代表电量不足；
-  轻推左手小油门，检查飞机是否能快速响应；
-  轻推右手方向，检查方向控制是否正确；
-  起飞吧！

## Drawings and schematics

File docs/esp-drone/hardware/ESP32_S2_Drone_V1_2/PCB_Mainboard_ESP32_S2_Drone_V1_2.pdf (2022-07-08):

100.0mm

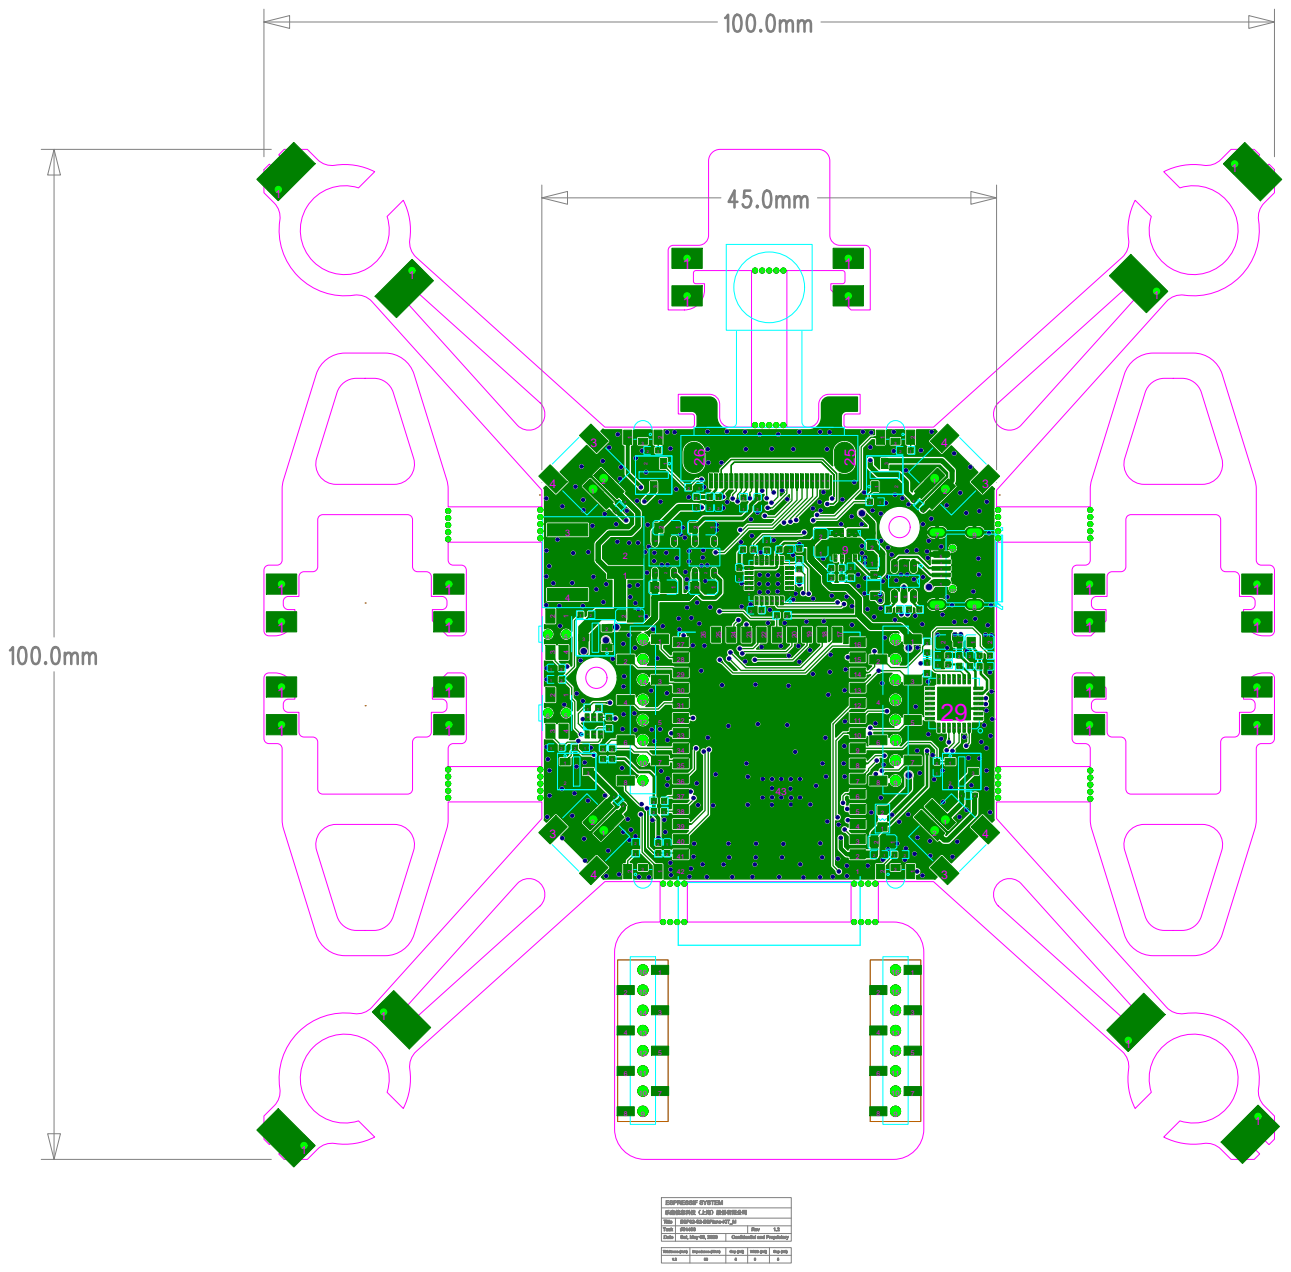
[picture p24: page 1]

100.0mm

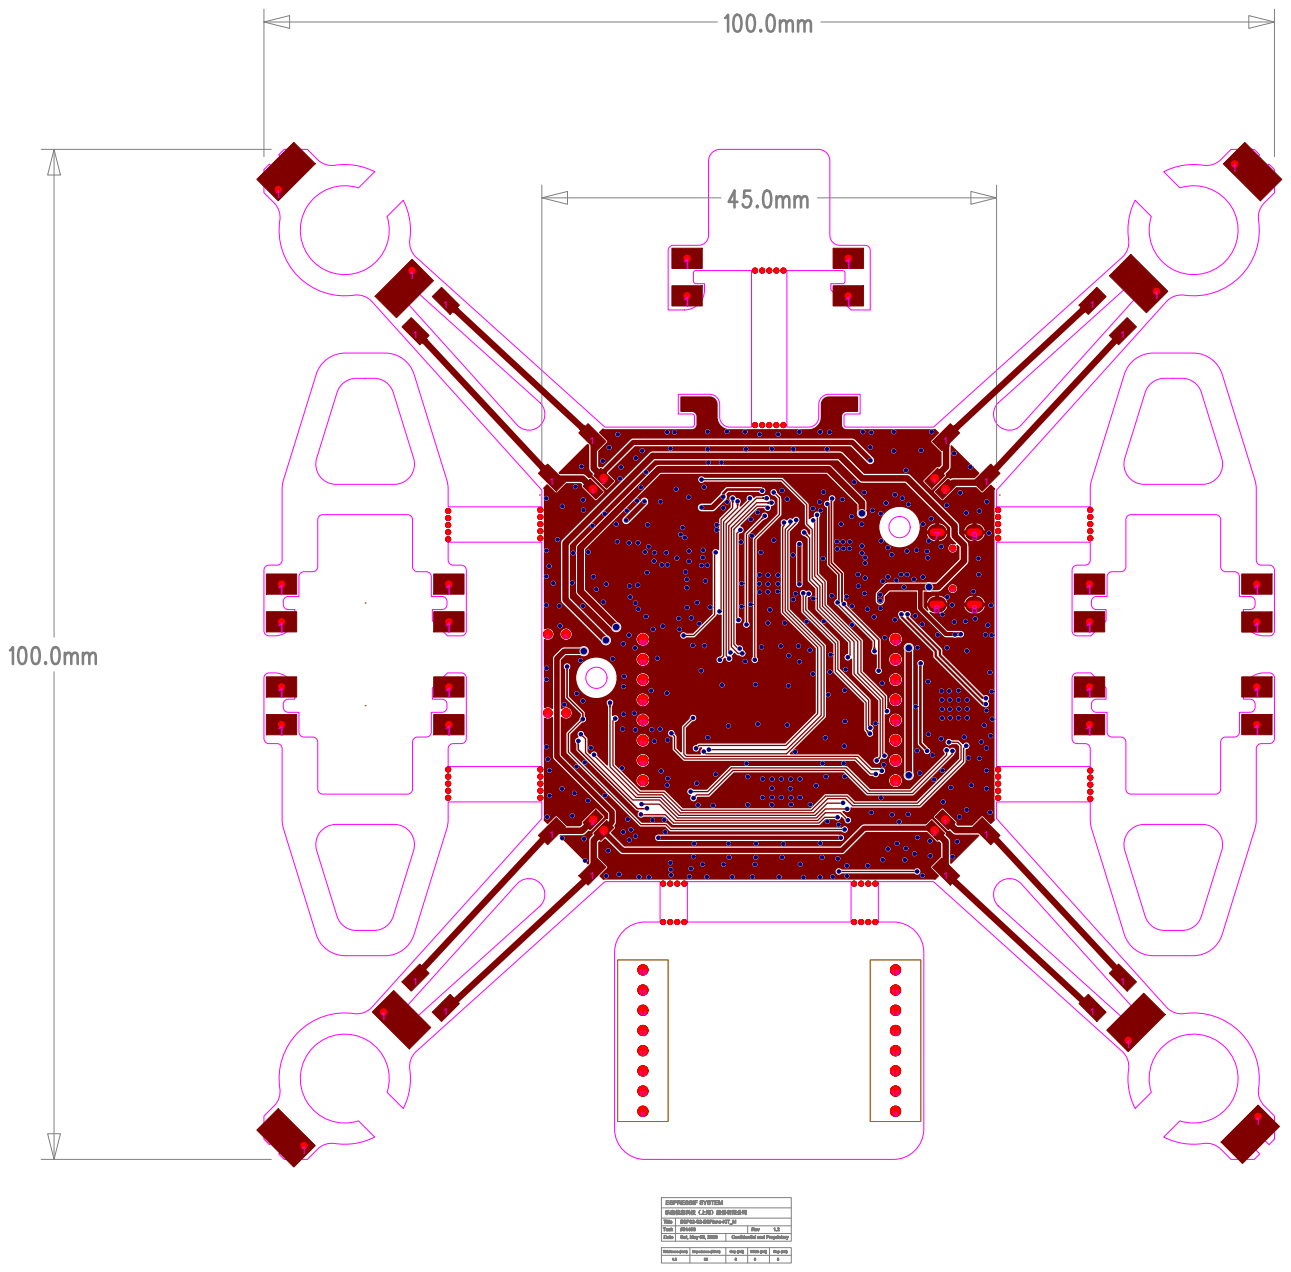
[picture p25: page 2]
Impedance (Ohm); Width (mil); Gap (mil) 5; Date; Task; Title; ESPRESSIF SYSTEM; Sat, May 09, 2020; Confidential and Proprietary; ESP32-S2-ESPlane-KIT_M; Rev; Thickness (mm); Gap (mil); H59H⁵⁹x1; H60H⁶⁰x1; H61H⁶¹x1; H62H⁶²x1; H63H⁶³x1; H65H⁶⁵x1; H66H⁶⁶x1; H67H⁶⁷x1; H68H⁶⁸x1; H69H⁶⁹x1; H70H⁷⁰x1; H71H⁷¹x1; H72H⁷²x1; H58H⁵⁸x1; H73H⁷³x1; H1H¹x1

乐鑫信息科技（上海）股份有限公司

100.0mm

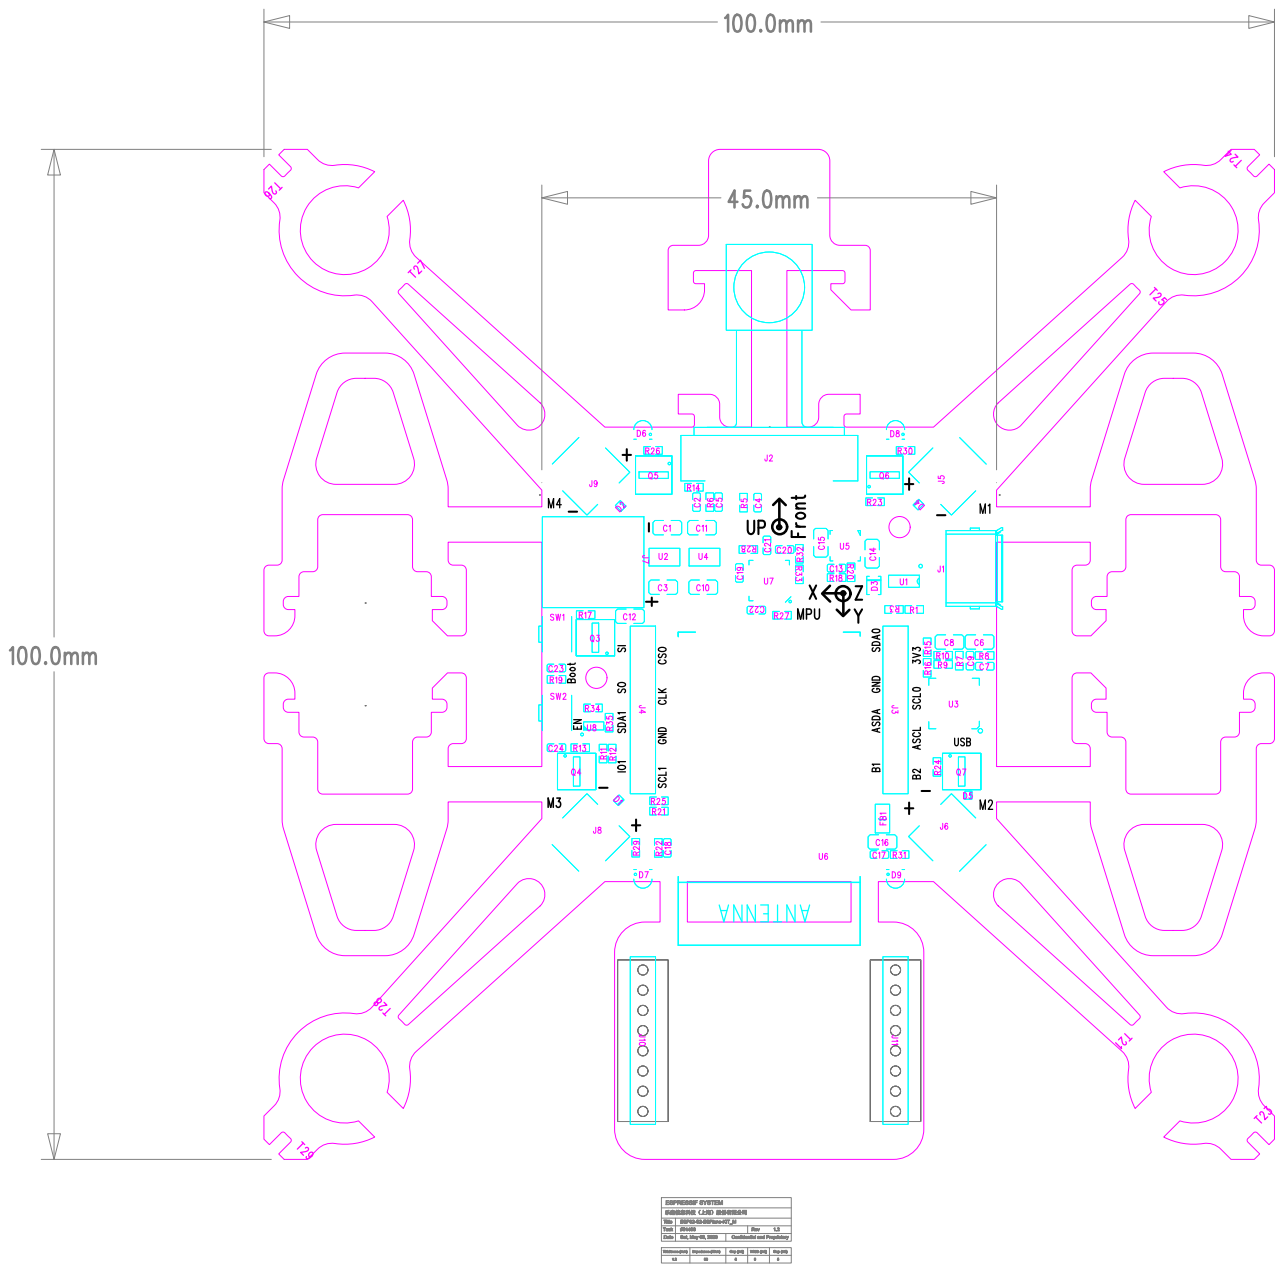
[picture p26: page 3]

100.0mm

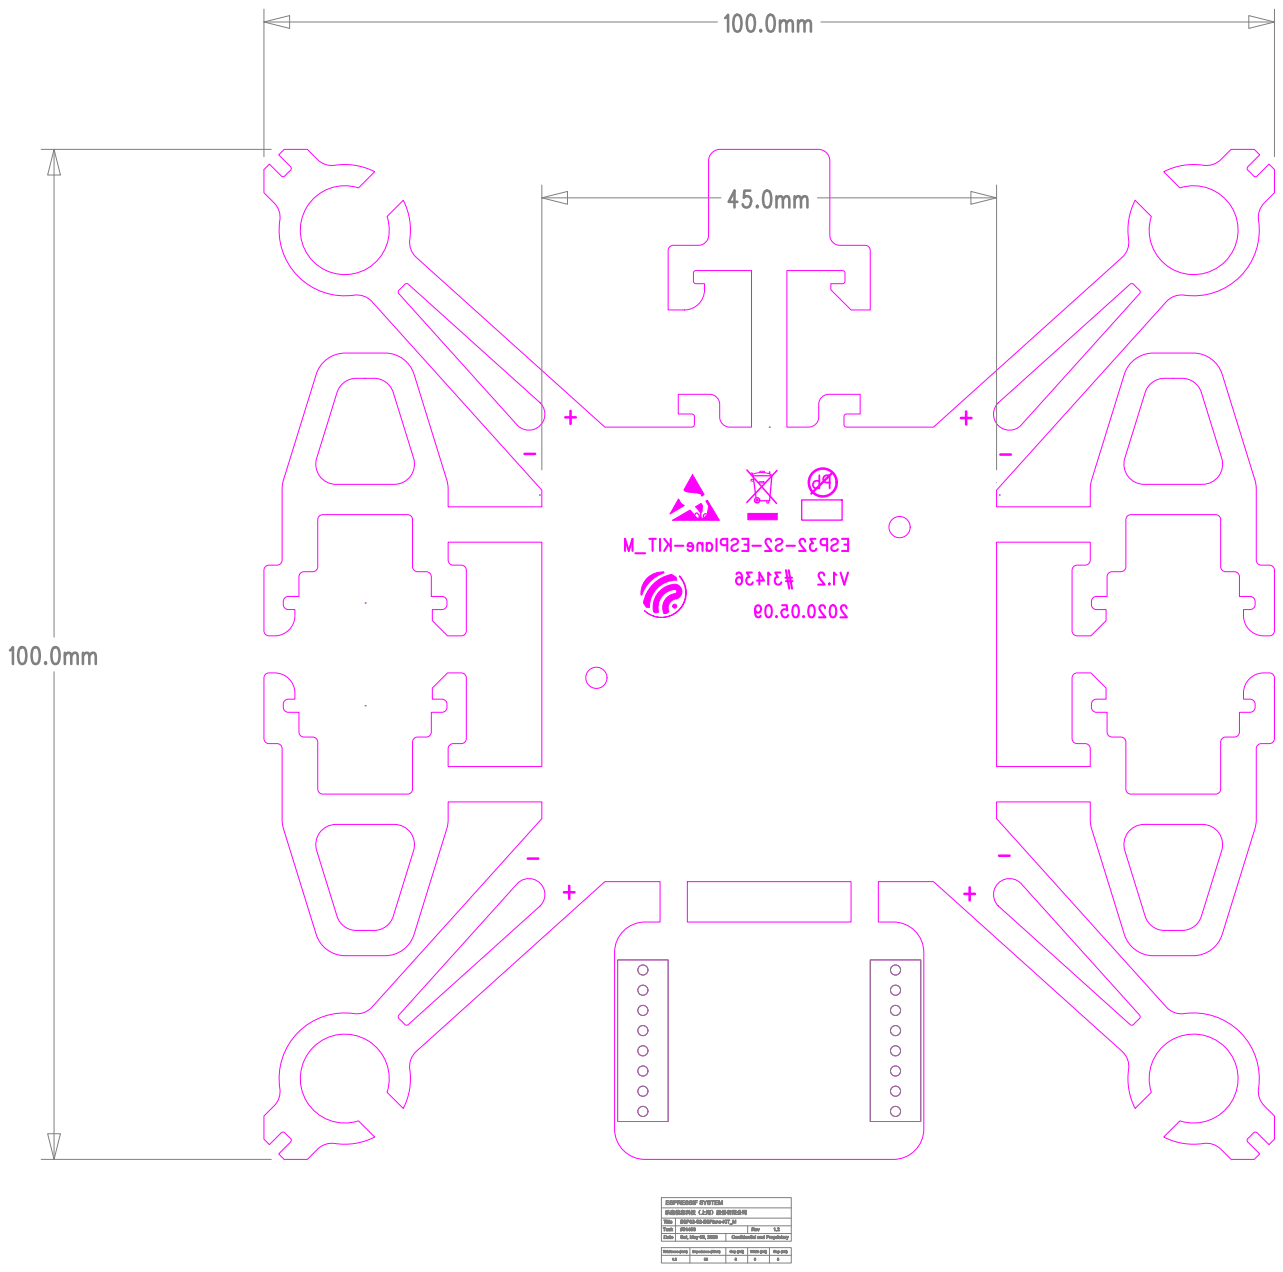
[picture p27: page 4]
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

乐鑫信息科技（上海）股份有限公司

100.0mm

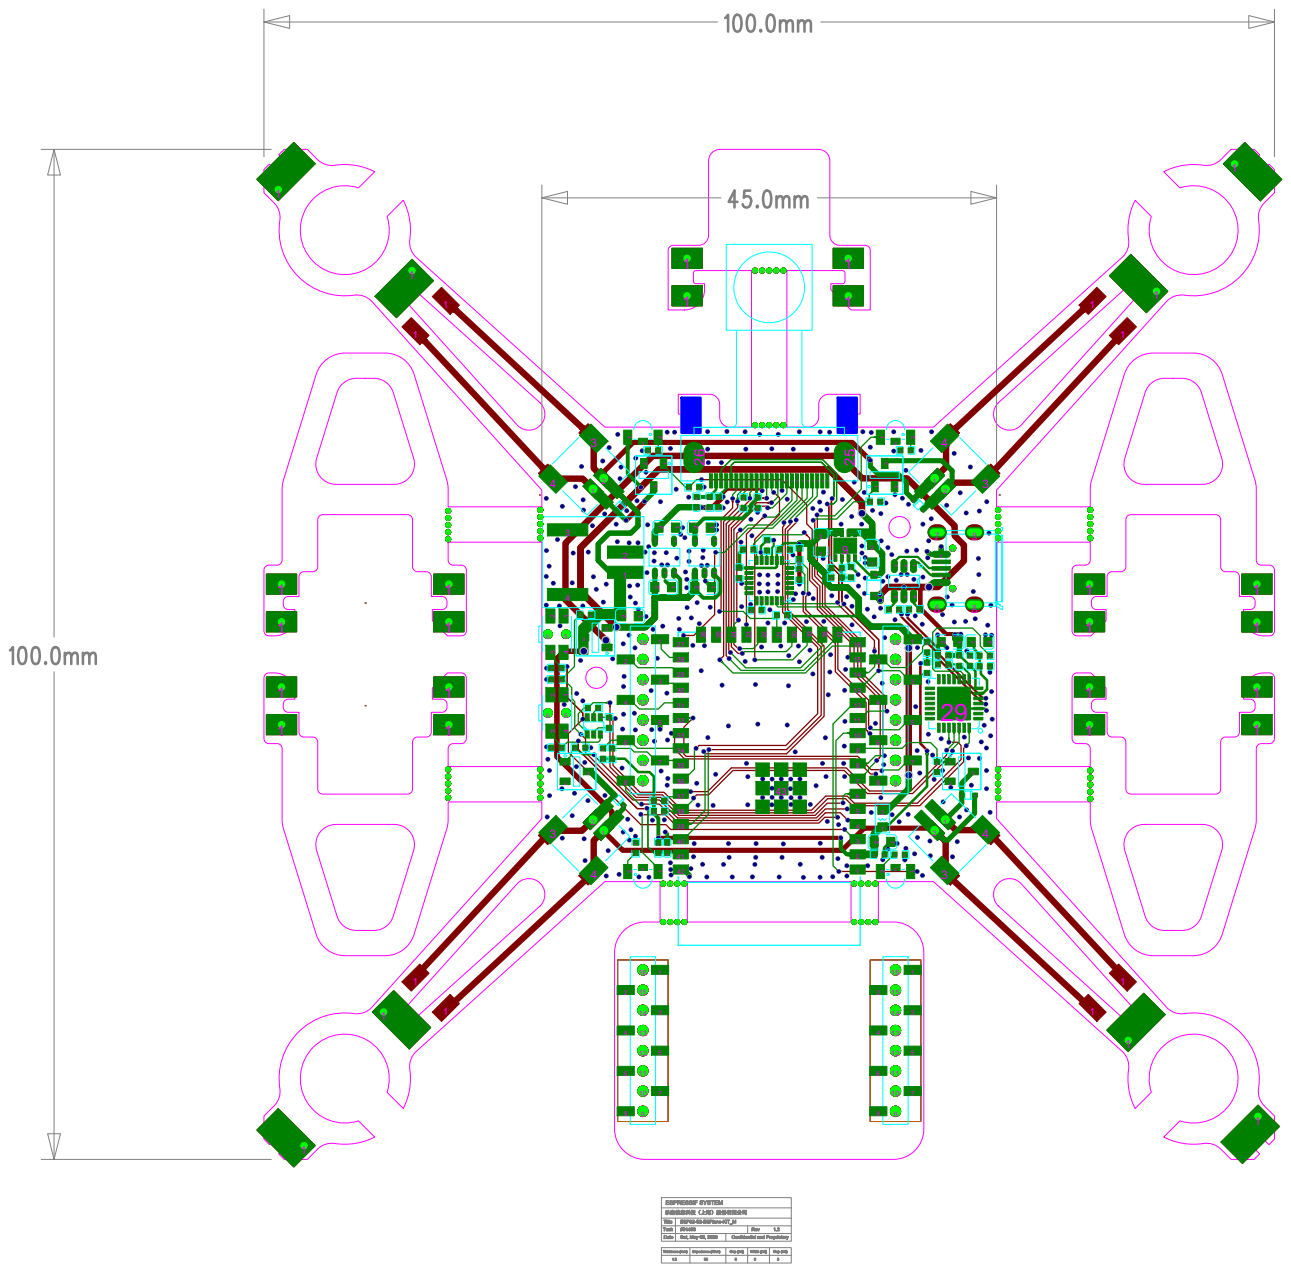
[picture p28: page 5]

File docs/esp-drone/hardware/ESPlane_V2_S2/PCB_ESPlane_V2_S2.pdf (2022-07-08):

45.0mm

J2J2x1 | J2x2 | J2x3 | J2x4 | J2x5 | J2x6 | J2x7 | J2x8 | J2x9 | J2x10 | J2x11 | J2x12 | J2x13 | J2x14 | J2x15 | J2x16 | J2x17 | J2x18 | J2x19 | J2x20 | J2x21 | J2x22 | J2x23 | J2x24 J2x26 | J2x25

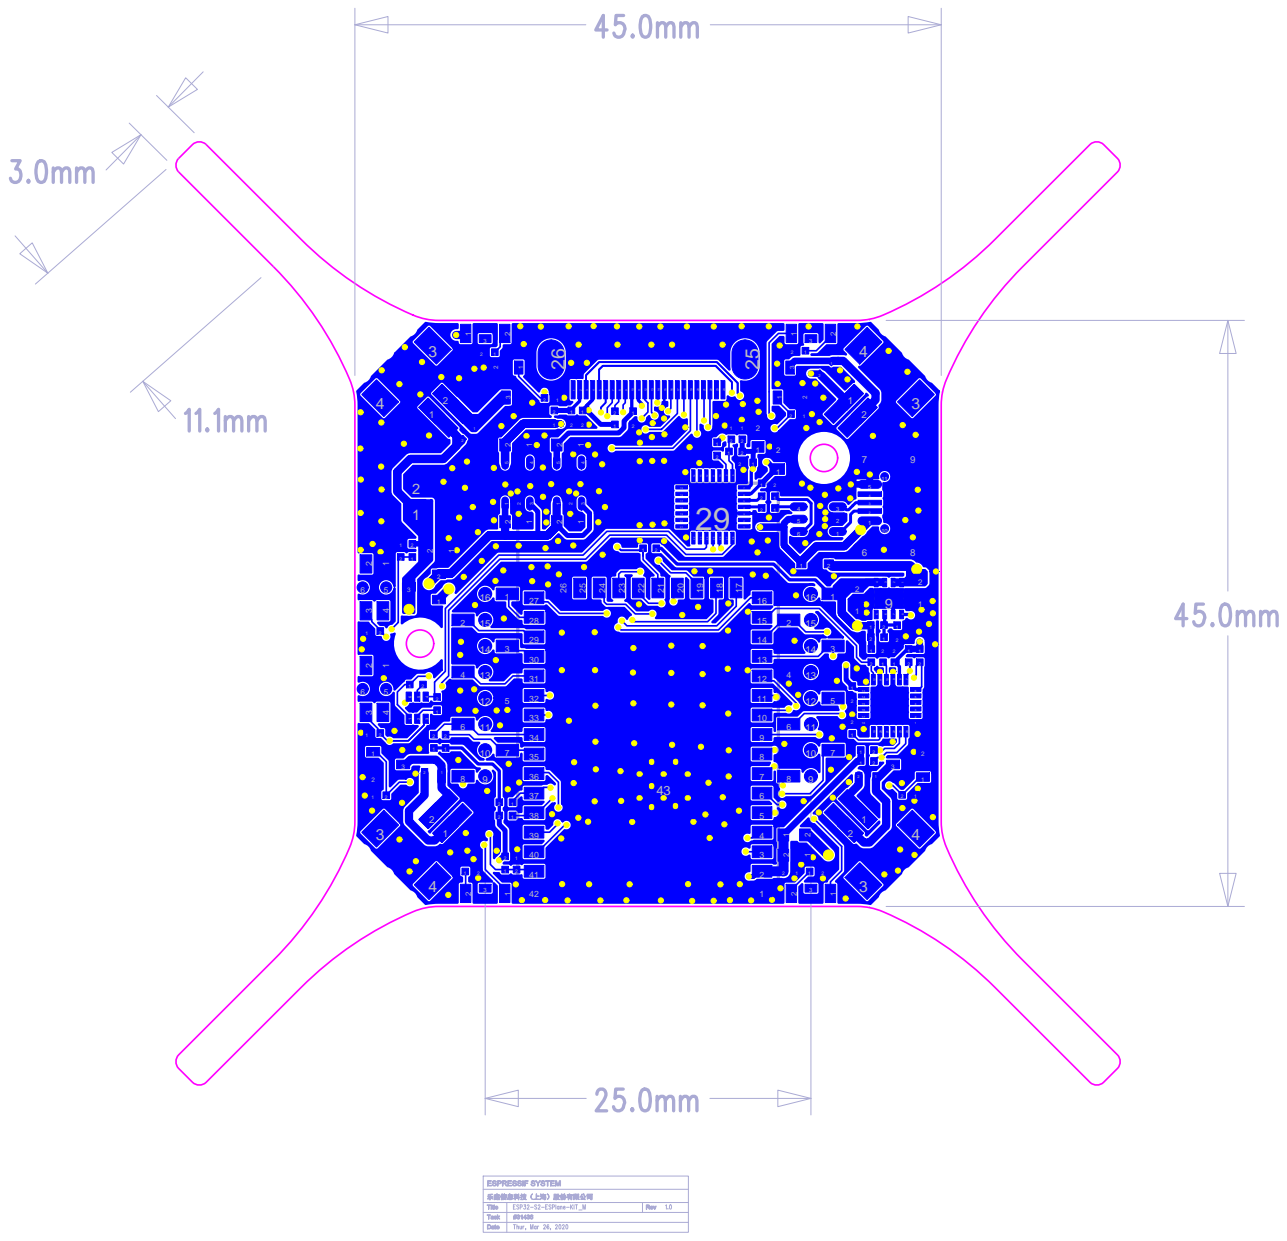
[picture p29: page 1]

45.0mm

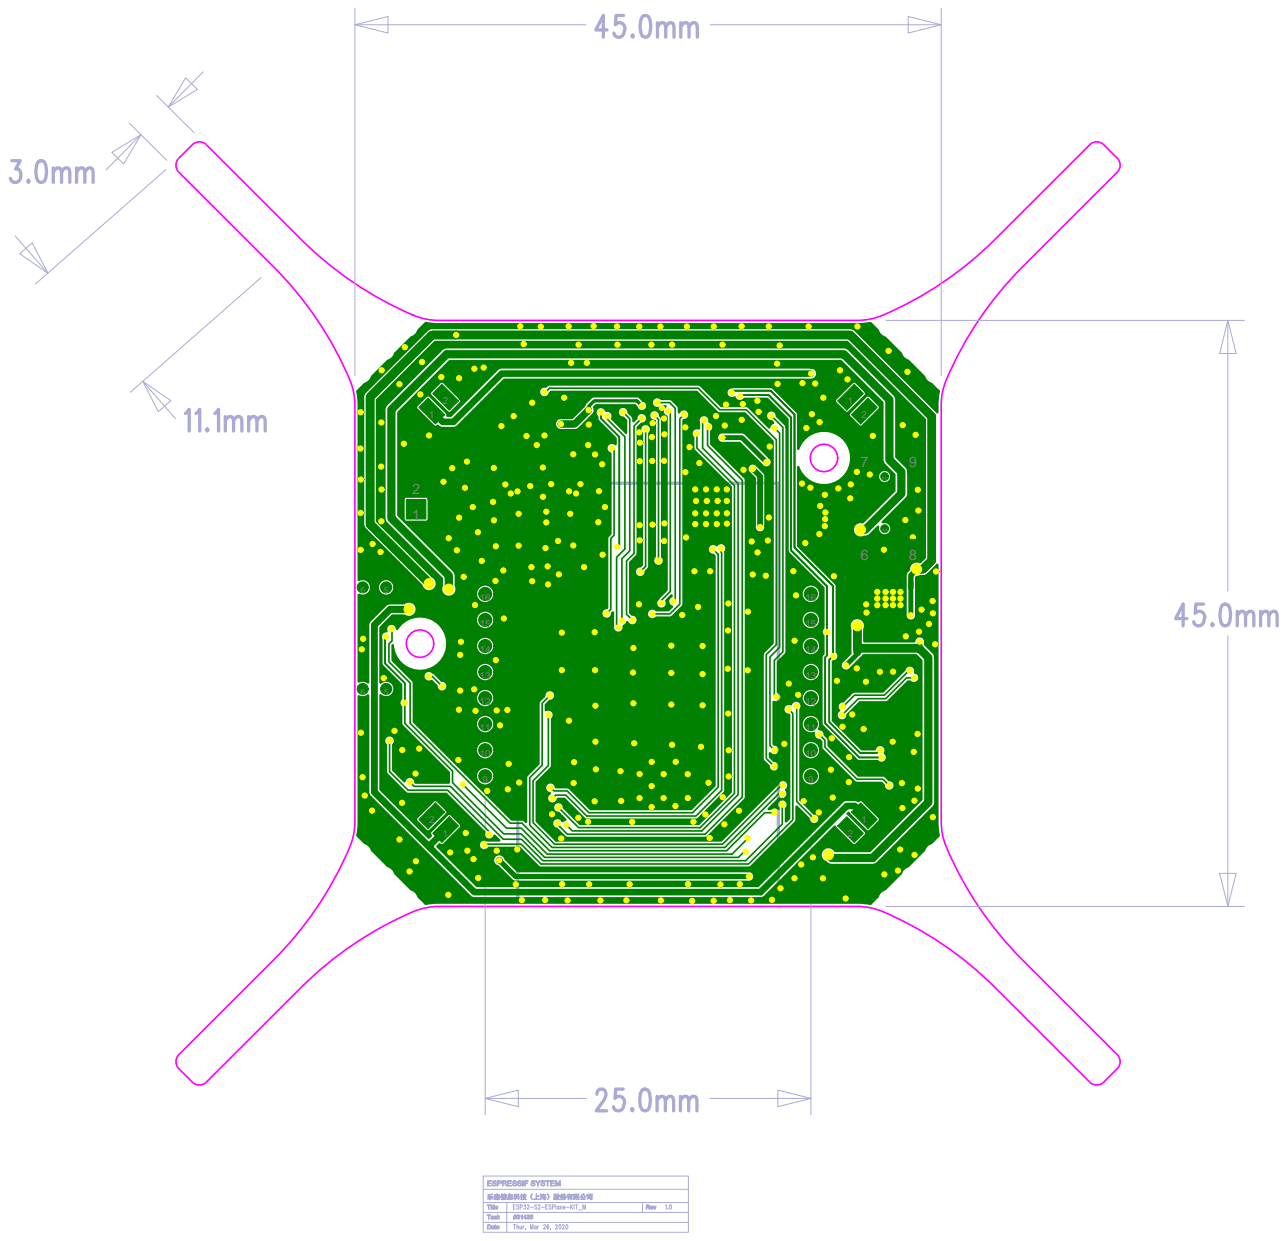
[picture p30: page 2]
Title; ESP32-S2-ESPlane-KIT_M; ESPRESSIF SYSTEM; Task; Date; Thur, Mar 26, 2020; Rev; SW1 SW¹x6; SW¹x5; SW2 SW²x6; SW²x5

乐鑫信息科技（上海）股份有限公司

45.0mm
J2

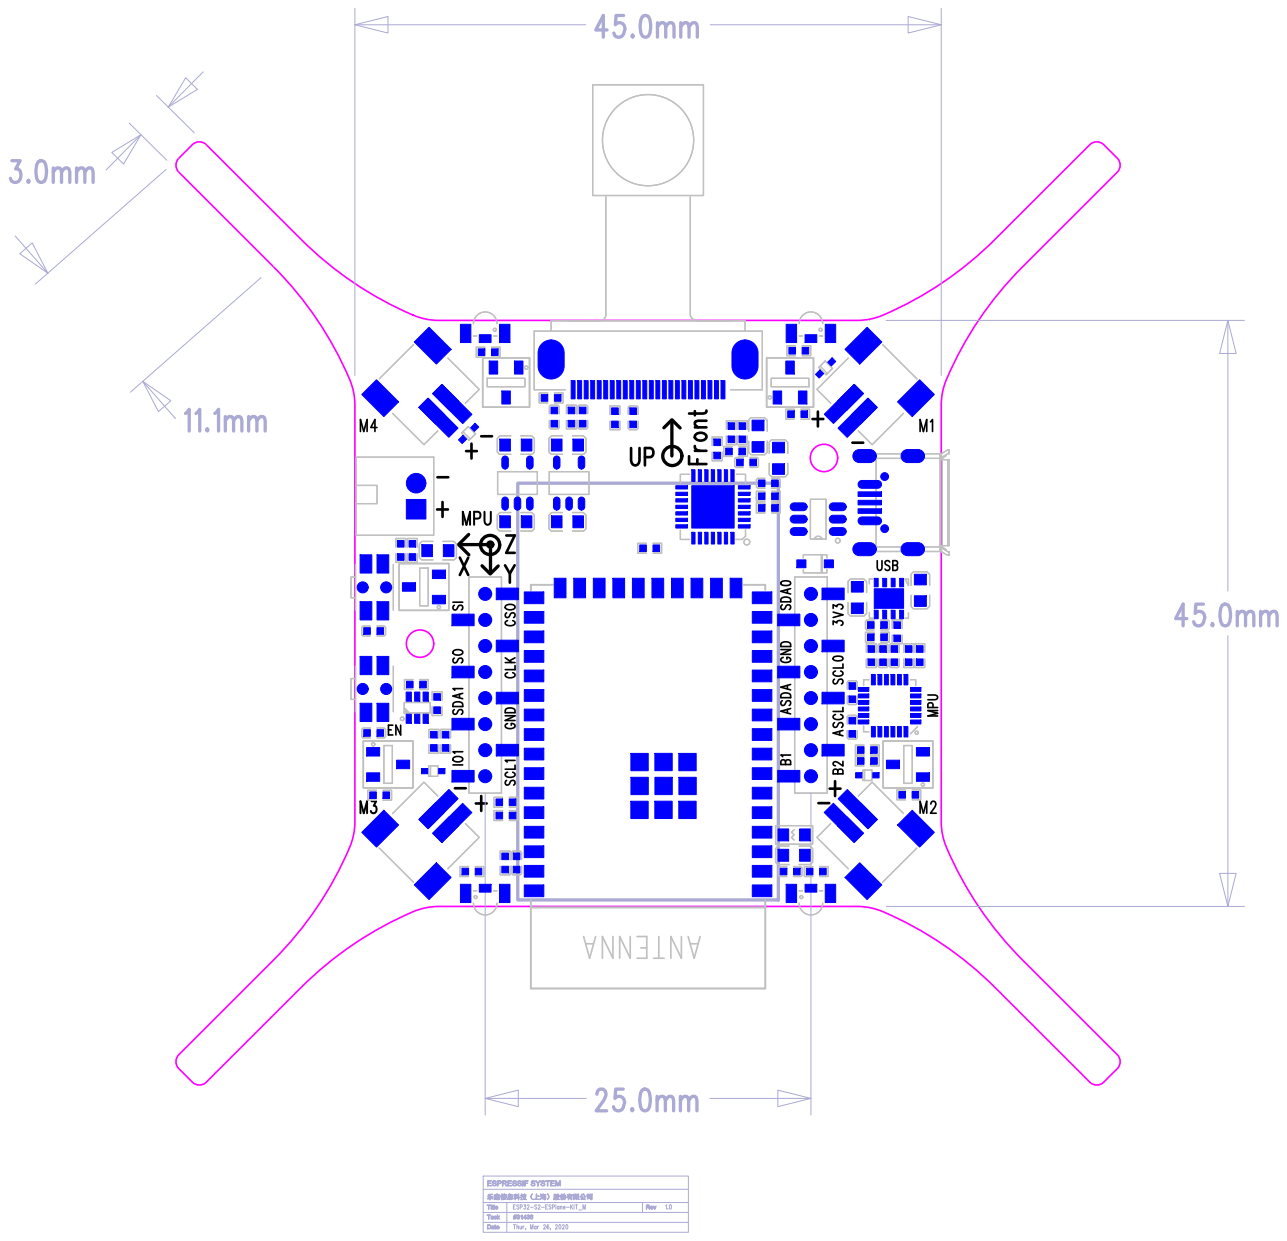
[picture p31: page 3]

45.0mm

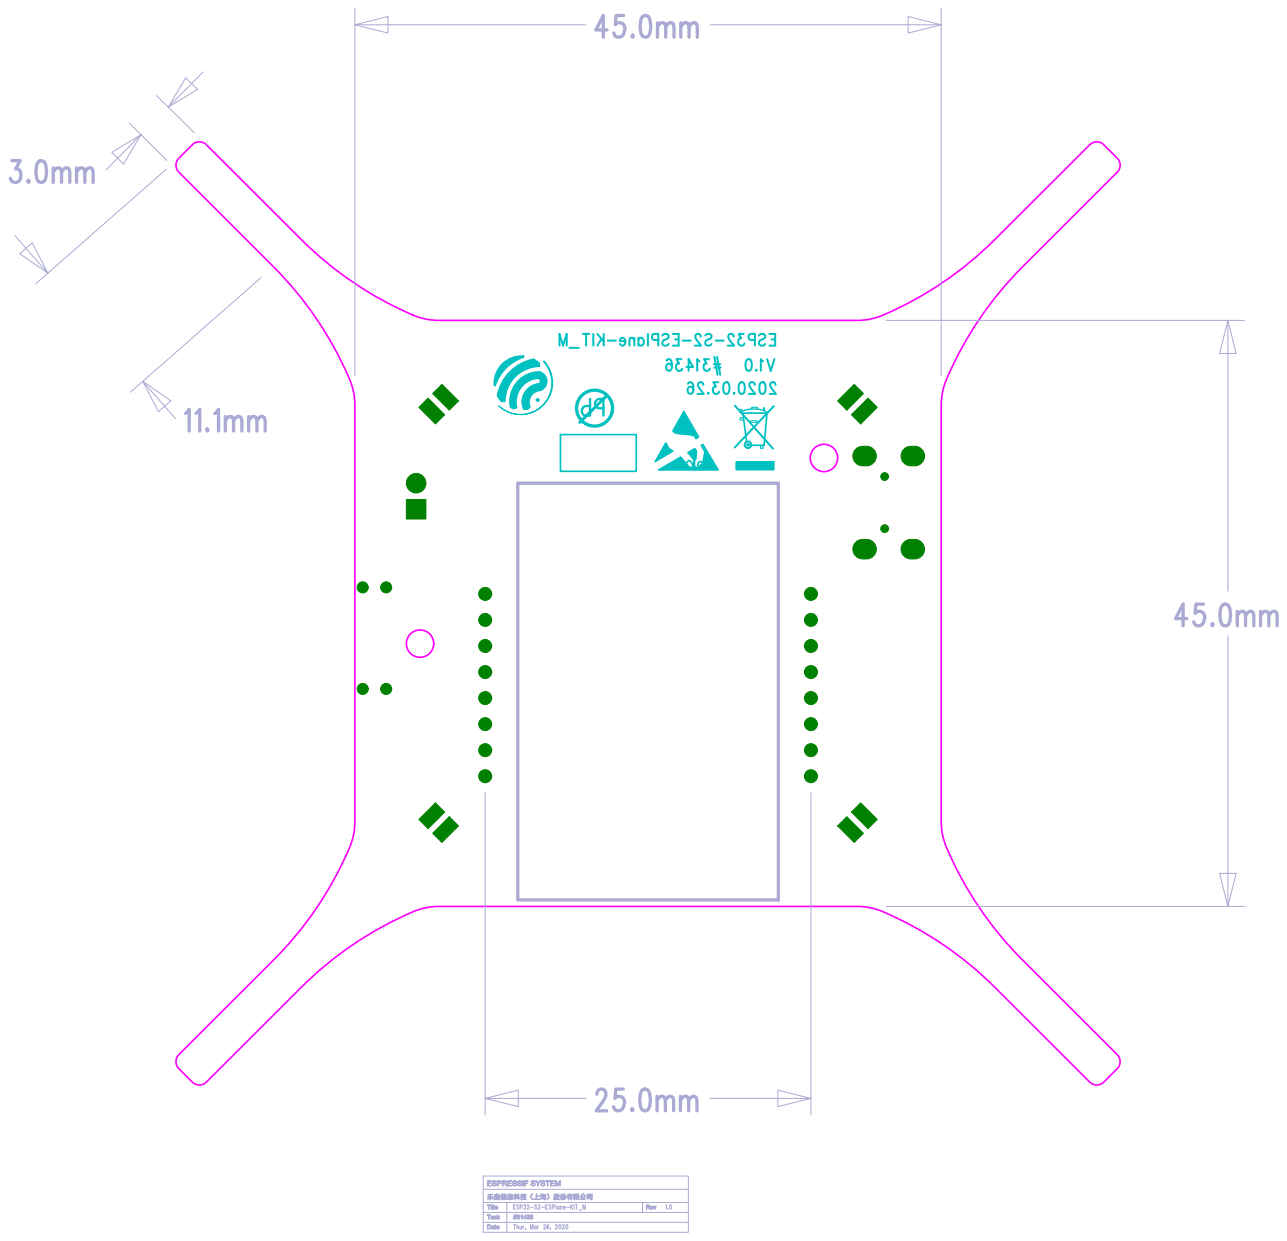
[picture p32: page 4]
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

乐鑫信息科技（上海）股份有限公司

45.0mm
J2

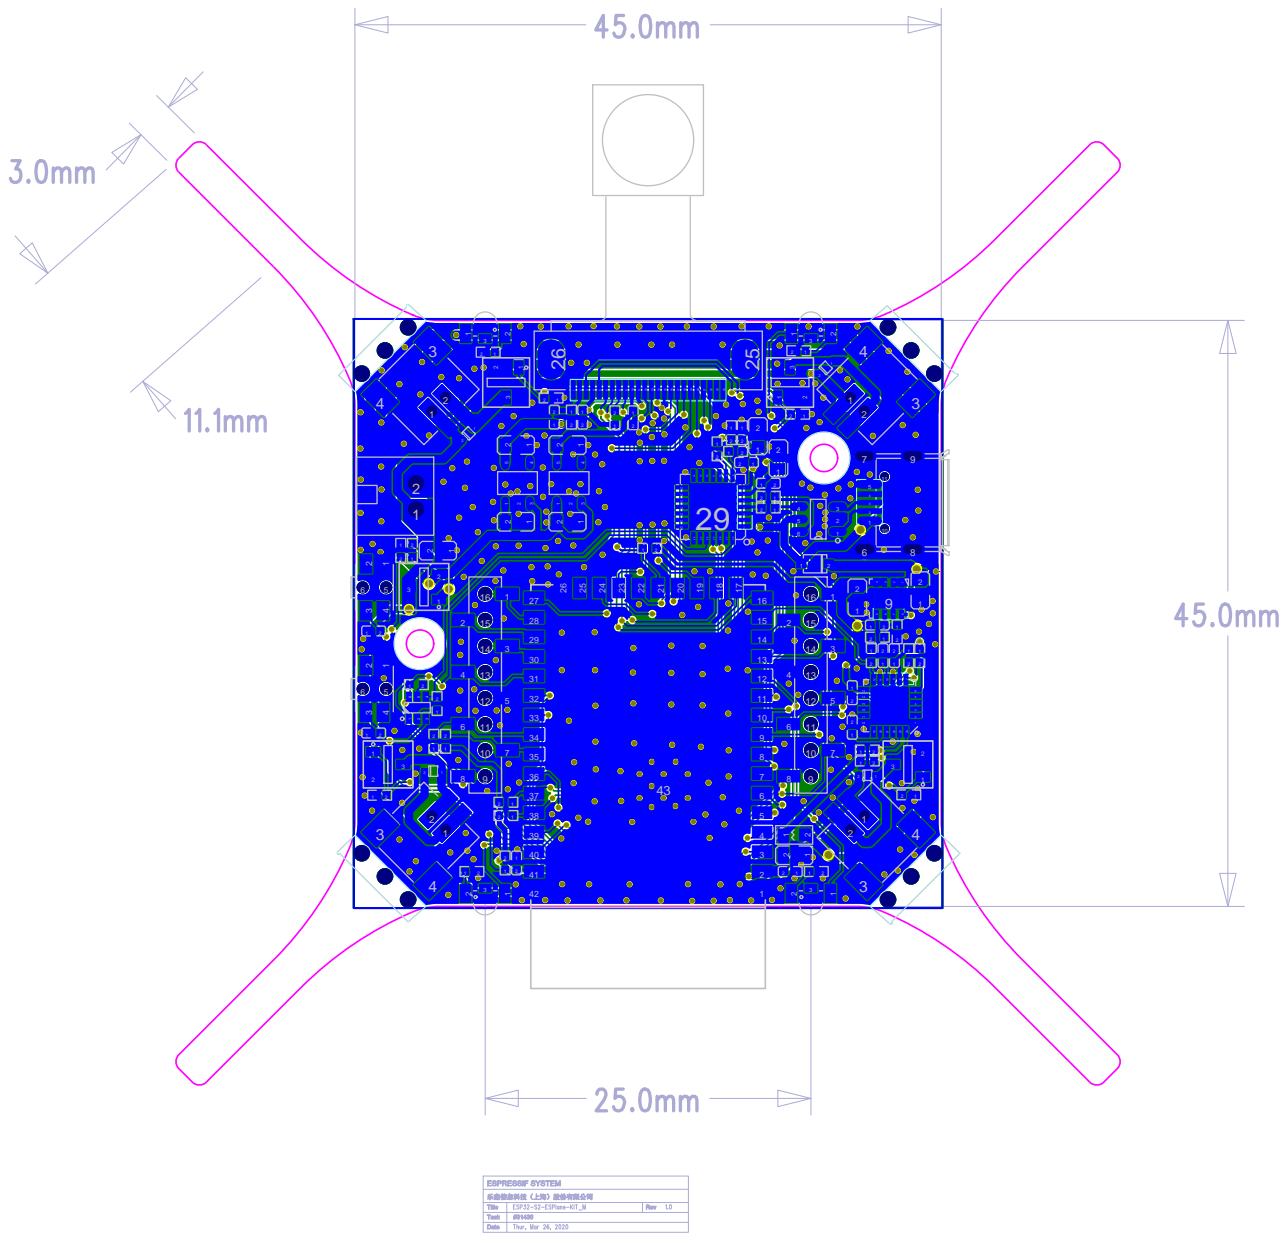
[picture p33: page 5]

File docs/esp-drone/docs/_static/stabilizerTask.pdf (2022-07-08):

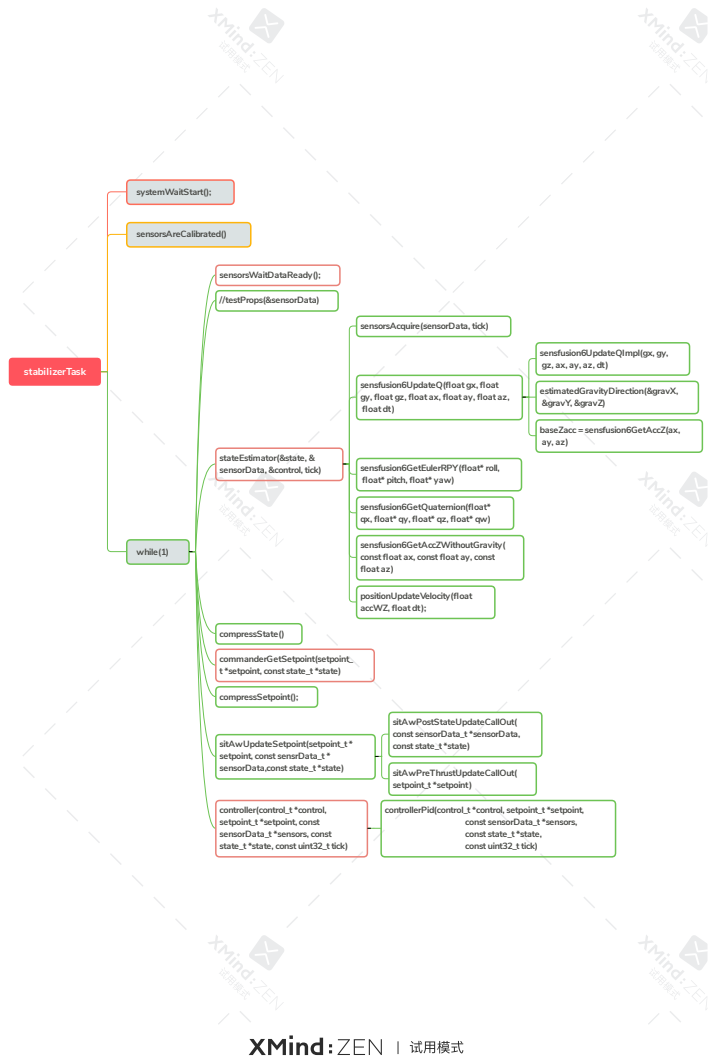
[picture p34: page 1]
stabilizerTask; systemWaitStart();; sensorsAreCalibrated(); while(1); sensorsWaitDataReady();; //testProps(&sensorData); estimatedGravityDirection(&gravX, &gravY, &gravZ); baseZacc = sensfusion6GetAccZ(ax, ay, az); compressState(); compressSetpoint();; sitAwPostStateUpdateCallOut( const sensorData_t *sensorData, const state_t *state); sitAwPreThrustUpdateCallOut( setpoint_t *setpoint)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

sensorsAcquire(sensorData, tick)

sensfusion6UpdateQImpl(gx, gy,

sensfusion6UpdateQ(float gx, float
gy, float gz, float ax, float ay, float az,
float dt)

stateEstimator(&state, &
sensorData, &control, tick)

sensfusion6GetEulerRPY(float* roll,
float* pitch, float* yaw)

sensfusion6GetQuaternion(float*
qx, float* qy, float* qz, float* qw)

sensfusion6GetAccZWithoutGravity(
const float ax, const float ay, const
float az)

positionUpdateVelocity(float
accWZ, float dt);

commanderGetSetpoint(setpoint_
t *setpoint, const state_t *state)

sitAwUpdateSetpoint(setpoint_t *
setpoint, const sensrData_t *
sensorData,const state_t *state)

controllerPid(control_t *control, setpoint_t *setpoint,

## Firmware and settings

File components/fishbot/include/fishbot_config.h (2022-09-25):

/**
 * @brief 文件描述：待更新
 * @author 小鱼 (fishros@foxmail.com)
 * @version V1.0.0
 * @date 2022-07-07
 * @copyright 版权所有：FishBot Open Source Organization
 */
#ifndef _FISHBOT_CONFIG_H_
#define _FISHBOT_CONFIG_H_

#include "led.h"
#include "motor.h"
#include "pid_controller.h"
#include "rotary_encoder.h"
#include "oled.h"
#include "mpu6050.h"
#include "wifi.h"
#include "protocol.h"
#include "store.h"
#include "key.h"

#define FISHBOT_SOFTWARE_VERSION_STRING_MAX_LEN (32 + 1)
#define FISHBOT_HARDWARE_VERSION_STRING_MAX_LEN (32 + 1)

// LED的数量
#define DEFAULT_LED_NUM 1
// 蓝色灯的ID
#define LED_BLUE 0
// 默认的电机数量
#define DEFAULT_MOTOR_NUM 2

#define WIFI_MODE_COONFIG_NAME "wifi_config"
#define PROTO_COONFIG_NAME "proto_config"

/**
 * @brief 系统配置结构体
 *
 */
typedef struct
{
    char driver_version[FISHBOT_SOFTWARE_VERSION_STRING_MAX_LEN];
    char hardware_version[FISHBOT_HARDWARE_VERSION_STRING_MAX_LEN];
    uint8_t motors_num;
} fishbot_config_t;

/**
 * @brief 初始化配置文件，从nvs中加载配置文件
 *
 * @return true
 * @return false
 */
bool fishbot_config_init();

/**
 * @brief 首次上电初始化配置
 *
 * @return true
 * @return false
 */
bool fishbot_first_startup_config_init();

/**
 * @brief 对外提供接口，获取配置文件
 *
 * @return const fishbot_config_t*
 */
const fishbot_config_t *fishbot_get_config(void);

/**
 * @brief 获取系统驱动版本信息
 *
 * @return const char* fbmch:fishbot motion control driver
 */
const char *fishbot_config_get_driver_version();

/**
 * @brief 获取系统硬件版本信息
 *
 * @return const char* fbmch:fishbot motion control hardware
 */
const char *fishbot_config_get_hardware_version();

const char *fishbot_config_get_proto_mode_str();
// update motor pid config
// update motor scale config
// update wifi config
// update udp server config
// update transform config

#endif // _FISHBOT_CONFIG_H_

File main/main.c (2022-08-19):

/**
 * @brief 启动入口文件
 * @author 小鱼 (fishros@foxmail.com)
 * @version V1.0.0
 * @date 2022-06-21
 * @copyright 版权所有：FishBot Open Source Organization
 */

#include "fishbot.h"

/**
 * @brief 主入口函数
 *
 */
void app_main(void)
{
    esp_err_t ret = nvs_flash_init();

    if (ret == ESP_ERR_NVS_NO_FREE_PAGES || ret == ESP_ERR_NVS_NEW_VERSION_FOUND)
    {
        ESP_ERROR_CHECK(nvs_flash_erase());
        ret = nvs_flash_init();
    }

    ESP_ERROR_CHECK(ret);

    if (fishbot_init() == false)
    {
        while (1)
            ;
    }
    fishbot_task_init();
}

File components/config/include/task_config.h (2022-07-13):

/**
 * @brief 文件描述：待更新
 * @author 小鱼 (fishros@foxmail.com)
 * @version V1.0.0
 * @date 2022-07-07
 * @copyright 版权所有：FishBot Open Source Organization
 */
#ifndef _TASK_CONFIG_H_
#define _TASK_CONFIG_H_

// // if task watchdog triggered,KALMAN_TASK_PRI should set lower or set lower flow frequency
// #ifdef TARGET_MCU_ESP32
// #define KALMAN_TASK_PRI 2
// #define LOG_TASK_PRI 1
// #define MEM_TASK_PRI 1
// #define PARAM_TASK_PRI 1
// #endif

#define SYSLINK_TASK_PRI 3
#define USBLINK_TASK_PRI 3
#define ACTIVE_MARKER_TASK_PRI 3
#define AI_DECK_TASK_PRI 3
#define UART2_TASK_PRI 3
#define WIFILINK_TASK_PRI 3
#define UDP_TX_TASK_PRI 3
#define UDP_RX_TASK_PRI 3
#define UDP_RX2_TASK_PRI 3

// Task names
#define SYSTEM_TASK_NAME "SYSTEM"
#define LEDSEQCMD_TASK_NAME "LEDSEQCMD"
#define ADC_TASK_NAME "ADC"
#define UART_RX_TASK_NAME "UART"
#define ACTIVE_MARKER_TASK_NAME "ACTIVEMARKER-DECK"
#define AI_DECK_GAP_TASK_NAME "AI-DECK-GAP"
#define AI_DECK_NINA_TASK_NAME "AI-DECK-NINA"
#define UART2_TASK_NAME "UART2"

#define configBASE_STACK_SIZE 512

// Task stack sizes
#define SYSTEM_TASK_STACKSIZE (6 * configBASE_STACK_SIZE)
#define LEDSEQCMD_TASK_STACKSIZE (2 * configBASE_STACK_SIZE)
#define ADC_TASK_STACKSIZE (1 * configBASE_STACK_SIZE)

#endif /* _TASK_CONFIG_H_ */

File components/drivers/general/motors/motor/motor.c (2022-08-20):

/**
 * @brief 文件描述：待更新
 * @author 小鱼 (fishros@foxmail.com)
 * @version V1.0.0
 * @date 2022-07-07
 * @copyright 版权所有：FishBot Open Source Organization
 */
#include "motor.h"

#define FISHBOT_MODLUE "MOTOR"

#ifdef DRIVER_USE_TB6612
#define UPDATE_OUTPUT(motor_id, output)                                     \
    if (output > 0)                                                         \
    {                                                                       \
        gpio_set_level(motor_config_[motor_id].io_positive, 1);             \
        gpio_set_level(motor_config_[motor_id].io_negative, 0);             \
        ledc_set_duty(LEDC_HIGH_SPEED_MODE, ledc_channel_map[motor_id],     \
                      (int)output);                                         \
        ledc_update_duty(LEDC_HIGH_SPEED_MODE, ledc_channel_map[motor_id]); \
    }                                                                       \
    else                                                                    \
    {                                                                       \
        gpio_set_level(motor_config_[motor_id].io_positive, 0);             \
        gpio_set_level(motor_config_[motor_id].io_negative, 1);             \
        ledc_set_duty(LEDC_HIGH_SPEED_MODE, ledc_channel_map[motor_id],     \
                      -1 * (int)output);                                    \
        ledc_update_duty(LEDC_HIGH_SPEED_MODE, ledc_channel_map[motor_id]); \
    }

#endif

#ifdef DRIVER_USE_DRV8833

#define UPDATE_OUTPUT(motor_id, output)                                                    \
    if (output > 0)                                                                        \
    {                                                                                      \
        ledc_set_duty(LEDC_HIGH_SPEED_MODE, ledc_channel_map[2 * motor_id], (int)output);  \
        ledc_update_duty(LEDC_HIGH_SPEED_MODE, ledc_channel_map[2 * motor_id]);            \
        ledc_set_duty(LEDC_HIGH_SPEED_MODE, ledc_channel_map[2 * motor_id+1], 0);           \
        ledc_update_duty(LEDC_HIGH_SPEED_MODE, ledc_channel_map[2 * motor_id+1]);            \
    }                                                                                      \
    else                                                                                   \
    {                                                                                      \
        ledc_set_duty(LEDC_HIGH_SPEED_MODE, ledc_channel_map[2 * motor_id], 0);           \
        ledc_update_duty(LEDC_HIGH_SPEED_MODE, ledc_channel_map[2 * motor_id]);            \
        ledc_set_duty(LEDC_HIGH_SPEED_MODE, ledc_channel_map[2*motor_id+1], -1 * (int)output); \
        ledc_update_duty(LEDC_HIGH_SPEED_MODE, ledc_channel_map[2*motor_id+1]);                \
    }

#endif

/*configs*/
static uint8_t motor_num_ = 0;
static pid_ctrl_config_t *pid_config_ = 0;
static motor_config_t *motor_config_ = 0;
static uint8_t ledc_channel_map[] = {LEDC_CHANNEL_0, LEDC_CHANNEL_1,
                                     LEDC_CHANNEL_2, LEDC_CHANNEL_3};

static pid_ctrl_block_handle_t
    pid_ctrl_block_handle_[MAX_MOTOR_NUM];               // PID控制结构体
static rotary_encoder_t *rotary_encoder_[MAX_MOTOR_NUM]; // 编码器配置
static int16_t target_speeds[MAX_MOTOR_NUM] = {0, 0};    // 电机当前速度，单位mm/s
static uint16_t tick_to_mms[MAX_MOTOR_NUM] = {
    62.011394, 62.011394}; // 电机的编码器和距离换算出的值
static proto_data_motor_encoder_t
    proto_motor_encoder_data_; // 上传存储的编码器数据

bool set_motor_config(uint8_t motor_num, motor_config_t *motor_configs,
                      pid_ctrl_config_t *pid_configs)
{
    motor_num_ = motor_num;
    pid_config_ = pid_configs;
    motor_config_ = motor_configs;
    return true;
}

uint8_t update_motor_pid_param(fishbot_pid_config_t *proto_pid_data)
{
    // pid_update_parameters(pid_ctrl_block_handle_[0],);
    return true;
}

uint8_t update_motor_spped_fun(
    proto_motor_speed_ctrl_data_t *motor_spped_ctrl)
{
    static uint8_t index;
    for (index = 0; index < motor_num_; index++)
    {
        target_speeds[index] = motor_spped_ctrl->motor_speed[index];
    }
    return index;
}

/**
 * @brief 初始化电机，编码器&PWM
 *
 * @return true
 * @return false
 */
bool motor_init(void)
{
    // get_config && init
    uint8_t i;
    gpio_config_t io_conf;
    ledc_timer_config_t ledc_timer = {
        .duty_resolution = LEDC_TIMER_13_BIT, // resolution of PWM duty
        .freq_hz = 5000,                      // frequency of PWM signal
        .speed_mode = LEDC_HIGH_SPEED_MODE,   // timer mode
        .timer_num = LEDC_TIMER_0,            // timer index
        .clk_cfg = LEDC_AUTO_CLK,             // Auto select the source clock
    };
    ESP_ERROR_CHECK(ledc_timer_config(&ledc_timer));

    for (i = 0; i < motor_num_; i++)
    {
        // 编码器初始化
        rotary_encoder_[i] =
            create_rotary_encoder(i, motor_config_[i].io_encoder_positive,
                                  motor_config_[i].io_encoder_negative);
        // pid 配置初始化
        pid_new_control_block(pid_config_ + i, pid_ctrl_block_handle_ + i);
    }

#ifdef DRIVER_USE_TB6612
    for (i = 0; i < motor_num_; i++)
    {
        // 方向控制IO初始化
        io_conf.intr_type = GPIO_INTR_DISABLE;
        io_conf.mode = GPIO_MODE_OUTPUT;
        io_conf.pin_bit_mask = (1ULL << motor_config_[i].io_positive) |
                               (1ULL << motor_config_[i].io_negative);
        io_conf.pull_down_en = 0;
        io_conf.pull_up_en = 1;
        gpio_config(&io_conf);
        gpio_set_level(motor_config_[i].io_positive, 0);
        gpio_set_level(motor_config_[i].io_negative, 0);

        // PWM初始化
        ledc_channel_config_t ledc_channel = {
            .channel = ledc_channel_map[i],
            .duty = 0,
            .gpio_num = motor_config_[i].io_pwm,
            .speed_mode = LEDC_HIGH_SPEED_MODE,
            .hpoint = 0,
            .timer_sel = LEDC_TIMER_0,
        };
        ESP_ERROR_CHECK(ledc_channel_config(&ledc_channel));
    }
#endif

#ifdef DRIVER_USE_DRV8833
    for (i = 0; i < motor_num_; i++)
    {
        // PWM通道1初始化
        ledc_channel_config_t ledc_channel1 = {
            .channel = ledc_channel_map[2 * i],
            .duty = 0,
            .gpio_num = motor_config_[i].io_positive,
            .speed_mode = LEDC_HIGH_SPEED_MODE,
            .hpoint = 0,
            .timer_sel = LEDC_TIMER_0,
        };
        ESP_ERROR_CHECK(ledc_channel_config(&ledc_channel1));
        // PWM通道2初始化
        ledc_channel_config_t ledc_channel2 = {
            .channel = ledc_channel_map[2 * i + 1],
            .duty = 0,
            .gpio_num = motor_config_[i].io_negative,
            .speed_mode = LEDC_HIGH_SPEED_MODE,
            .hpoint = 0,
            .timer_sel = LEDC_TIMER_0,
        };
        ESP_ERROR_CHECK(ledc_channel_config(&ledc_channel2));
    }
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

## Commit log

2022-03-06 [feat]:添加v0.1原理图和PCB
    [PCB_fishbotv0.1_2022-03-06.pcbdoc, fishbotv0.1_2022-03-06.schdoc]
2022-03-06 [feat]:V0.1版本代码
2022-07-03 [feat]:完成LED&编码器驱动
2022-07-05 [tmp]:临时提交未测试PID
2022-07-06 [feat]:添加参考代码
    [BOM(0.2)_ESP32-S2-Drone_V1.2_20200512.xlsx, SCH_Mainboard_ESP32_S2_Drone_V1_2.DSN]
2022-07-06 [feat]:添加i2c和nvs样例代码
2022-07-06 [feat]:调整代码结构，增加文档信息
2022-07-07 feat(oled&i2c): 添加i2c和oled支持未测试
2022-07-07 feat(mpu6050): 完成MPU6050驱动
2022-07-08 feat(wifi): 增加WIFI驱动&优化速度
2022-07-08 feat(通信):增加uart-fishbot协议，支持发送和接收传感器、pid等信息
2022-07-08 fix(motor): 修复电机PWM无效问题
2022-07-10 to(protocol): 临时提交保存框架设计未完成
2022-07-10 to(protocol): 临时提交2保存框架设计未完成
2022-07-10 to(protocol): 根据书里架构完成新建代码文件
2022-07-10 to(protocol): 打通protocol初始化流程
2022-07-11 to(protocol): 优化转义与帧解析函数
2022-07-11 to(protocol): 调试串口可以正常输出
2022-07-12 to(protocol): 完善协议解析和发送部分函数定义
2022-07-13 feat(protcol): 整体协议框架已确定
2022-07-13 docs(readme): 添加TODO&DONE
2022-07-23 feat(mpu6050): 完成使用mpu原始数据计算欧拉角 (#5)
2022-07-23 feat(motor&protocol): 完成电机控制和协议部分功能 (#6)
    * feat(motor): 完成电机PID控制
    * to(protoc): 增加设置电机编码器函数
    * to(udp_client): 进一步完善初始化函数
    * to(protocol): 完善数据发送协议转义操作
    * to(protocol): 调试完成完整的电机数据帧组合
    * test(protocol): 测试数据内存对齐问题
    * fix(protcol): 修复未传输数据数量错误
    * feat(mpu6050): 添加滤波可能会用到的库
    * fix(protocol): 修复数据帧数据数量赋值错误&CRC校验错误
    * feat(motor): 调通串口控制电机速度
    * to(udp_protocol): 添加UDP协议部分配置
    * feat(udp_protocol): 完成UDPCLIENT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
    [fishbot_config.c, motor.c, proto_v1.0.0.20220621.c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]
2022-07-24 feat(protocol): 打通IMU数据发送 (#7)
2022-07-24 feat(hardware): 完成V1.0.0.220724_alpha原理图PCB绘制 (#8)
    * feat(hardware): 完成fbmcv1.0.0.220724原理图PCB设计
    * del(hardware): 删除多余PCBDOC
    [PCB_fishbotv0.1_2022-03-06.pcbdoc, fishbotv0.1_2022-03-06.schdoc]
2022-08-01 fix(motor): 修复引脚错误&增加motor任务速度
2022-08-02 feat(motor): 切换左右电机序号
2022-08-19 feat(protocol): 添加UDPServer支持
2022-08-19 feat(ptotocol): 添加几个结构体
2022-08-19 feat(protocol): 添加设备重启指令
2022-08-19 feat(nvs): 添加flash存储读取代码
2022-08-19 feat(nvs&proto): 完成掉电存储和WIFI设置
2022-08-19 feat(config): 完成wifi配置和通讯协议配置
2022-08-19 feat(device): 完成配置设备模式功能
2022-08-20 feat(oled): 修改OLED显示字体为6*8
2022-08-20 feat(key): 完成按键驱动切换模式
2022-08-20 feat(motor): 完成对drv8833的切换
2022-09-20 feat:修改mpu6050，增加mpu9250驱动 (#12)
2022-09-25 feat(oled): 添加通讯模式显示功能
